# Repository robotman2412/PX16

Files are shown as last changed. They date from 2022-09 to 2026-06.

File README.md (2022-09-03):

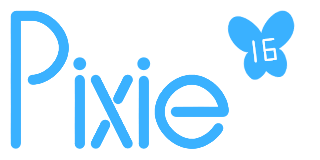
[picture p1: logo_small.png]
Logo image


# Pixie 16
A 16-bit simple-as-possible\* RISC CPU.
Has conditional `MOV` instructions (which is also how branching happens),
And a few math instructions.

Has 4 general registers: `R0`, `R1`, `R2`, `R3`
And 3 special registers: `ST` (stack register), `PF` (flags register), `PC` (program counter)

64K x 16bit memory.

### Note:
RISC is not equal to RISC-V.

PX16 cannot address bytes.

# TODO
Stuf i do be workin on:
- PCB edition
- Emulator
- Finalise MMIO Hardware
- C Compiler

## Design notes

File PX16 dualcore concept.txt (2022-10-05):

Requirements for multicore:
	- Alt core startup system
	- Core detection
	- Mutex hardware
	- Memory sharing plan

Nice-to-haves:
	- Core affine MMIO copies
	- Core affine RAM
	- Inter-Processor interrupts
	- Dual port RAM

When all the nice to haves are included, the cores are linked by:
	RAM (non-core affine part)
	Inter-Processor interrupts
	Mutex hardware

Viability:
	Dual port RAM chips are expensive, which means most likely dedicated circuitry.
	Dual port ROM is basically not a thing, which means that ROM must be copied before use.
	
	Creating two copies of all MMIO will be expensive and time-consuming because combined MMIO might be more complex than the core.
	
	Correctly coded software should not be affected, despite OS changes.

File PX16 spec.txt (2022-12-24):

Instruction format:
15.. .... .... ...0
YXXX BBBA AAOO OOOO

O: Opcode
A: A operand register
B: B operand register
X: Complex operand mode
Y: Apply complex operand to B instead of A

            .0  .1  .2  .3  .4  .5  .6  .7
0.  MATH2   ADD SUB CMP AND OR  XOR
1.  MATH2C  ADD SUB CMP AND OR  XOR
2.  MATH1   INC DEC CMP             SHL SHR
3.  MATH1C  INC DEC CMP             SHL SHR
4.  MOV.C   ULT UGT SLT SGT EQ  CS  1
5.  MOV.C   UGE ULE SGE SLE NE  CC  JSR CX
6.  LEA.C   ULT UGT SLT SGT EQ  CS  1
7.  LEA.C   UGE ULE SGE SLE NE  CC  JSR

Note: Because CMP is much like SUB, CMP is still valid for MATH1.

Registers:
R0, R1, R2, R3, ST, PF, PC, imm

Addressing modes:
    0: AR0  [A+R0]
    1: AR1  [A+R1]
    2: AR2  [A+R2]
    3: AR3  [A+R3]
    4: AST  [A+ST]
    5: MEM  [A]
    6: APC  [A+PC]
    7: IMM   A

Conditions:
    0:    ULT: Unsigned A < B; ~UCout ~Zero
    1:    UGT: Unsigned A > B;  UCout ~Zero
    2:    SLT: Signed A < B;   ~SCout ~Zero
    3:    SGT: Signed A > B;    SCout ~Zero
    4:    EQ:  Unsigned A = B;         Zero
    5:    CS:  Unsigned cout;   UCout
    6:    1:   Always true
    7:    -
    8-13: Opposite condition of 0-5
    14:   JSR: Used for creating subroutines
    15:   CX:  Used for carry extend

Enable IRQs and NMIs:
    OR  PF, 0x0003

Disable IRQs:
    AND PF, 0xfffd

Jump:
    LEA PC, [PC+imm]

Jump to subroutine:
    LEA.JSR PC, [PC+imm]

Return from subroutine:
    MOV PC, [ST]

Return from interrupt:
    // PX16 will not trigger interrupts immediately after this instruction.
    // This allows the return from interrupt to be 2 typical instructions.
    MOV PF, [ST]
    MOV PC, [ST]

Flag register (PF) layout:
15.. .... .... ...0
SUZ. .... .... PSIN
S: Signed carry out
U: Unsigned carry out
Z: Zero
P: Interrupt in progress
S: Interrupt was software triggered
I: IRQ enable
N: NMI enable

States:
    Boot: Load address 2 and set PC to it's value
        Boot 0: Set PC to 1
        Boot 1: Set PC to *2 by means of *(PC+1)
    Load:
        Load 0: Fetch and decode instruction
        Load 1: Fetch imm0
        Load 2: Fetch imm1
    Push: Pre-decrement ST
    Jsr:  Push PC to stack
    Addr: Address calculation and memory access
    Act:  Enact the instruction
    Pop:  Post-increment ST
    Intr:
        Intr 0: Pre-decrement ST
        Intr 1: Push PC to stack
        Intr 2: Pre-decrement ST
        Intr 3: Push PF to stack and set interrupt in progress flag
        Intr 4: Set PC to interrupt vector (*0 for IRQ, *1 for NMI)

State matrix:
            INC WR  WM  RM  W       AIA AIB AXA AXB Cin     ADD OR  XOR SHL SHR     A   B   Dst Si0 Si1
    Boot 0: -   1   -   -   -       -   -   -   1   1       1   -   -   -   -       6   -   6   -   -
    Boot 1: -   1   -   1   -       -   -   -   1   1       1   -   -   -   -       6   -   6   -   -
    
    Load 0: 1   -   -   1   -       -   -   1   -   -       -   1   -   -   -       -   6   -   -   -
    Load 1: 1   -   -   1   -       -   -   1   -   -       -   1   -   -   -       -   6   -   1   -
    Load 2: 1   -   -   1   -       -   -   1   -   -       -   1   -   -   -       -   6   -   -   1
    
    Push:   -   1   -   -   -       -   1   -   1   -       1   -   -   -   -       4   -   4   -   -
    Jsr:    -   -   1   -   -       -   -   1   -   -       -   1   -   -   -       -   6   -   -   -
    Addr:   Depends on addressing mode
    Mov:    Depends on opcode
    Act:    Depends on opcode
    Pop:    -   1   -   -   -       -   -   -   1   1       1   -   -   -   -       4   -   4   -   -
    
    Intr 0: -   1   -   -   -       -   1   -   1   -       1   -   -   -   -       4   -   4   -   -
    Intr 1: -   -   1   -   -       -   -   1   -   -       -   1   -   -   -       -   6   -   -   -
    Intr 2: -   1   -   -   -       -   1   -   1   -       1   -   -   -   -       4   -   4   -   -
    Intr 3: -   -   1   -   -       -   -   1   -   -       -   1   -   -   -       -   5   -   -   -
    Intr 4: -   1   -   1   -       -   -   1   -   -       -   1   -   -   -       -   -   6   -   -
    
Addressing matrix:
    AR*     -   -   -   1   -       -   -   -   -   -       1   -   -   -   -       X   Ry  -   -   -
    IMM:    Skip addr
    MOV     -   -   -   -   -       -   -   1   -   -       -   1   -   -   -       -   B   -   -   -
    MEM     -   -   -   1   -       -   -   1   -   -       -   1   -   -   -       -   Ry  -   -   -
    
    LEA     -   -   -   0   1       -   -   -   -   -       -   -   -   -   -       -   -   A   -   -
    MOV     -   -   -   -   1       -   -   -   -   -       -   -   -   -   -       -   -   A   -   -
    ACT     -   -   -   -   -       -   -   -   -   -       -   -   -   -   -       -   -   -   !Y  Y
    
Calculation matrix:
    ADD     -   -   -   -   1       -   -   -   -   -       1   -   -   -   -       A   B   A   -   -
    SUB     -   -   -   -   1       -   1   -   -   1       1   -   -   -   -       A   B   A   -   -
    CMP     -   -   -   -   -       -   1   -   -   1       1   -   -   -   -       A   B   A   -   -
    AND     -   -   -   -   1       1   1   -   -   -       -   1   -   -   -       A   B   A   -   -
    OR      -   -   -   -   1       -   -   -   -   -       -   1   -   -   -       A   B   A   -   -
    XOR     -   -   -   -   1       -   -   -   -   -       -   -   1   -   -       A   B   A   -   -
    
    INC     -   -   -   -   1       -   -   -   1   1       1   -   -   -   -       A   B   A   -   -
    DEC     -   -   -   -   1       -   1   -   1   -       1   -   -   -   -       A   B   A   -   -
    CMP     -   -   -   -   -       -   1   -   1   -       1   -   -   -   -       A   B   A   -   -
    SHL     -   -   -   -   1       -   -   -   1   -       -   -   -   1   -       A   B   A   -   -
    SHR     -   -   -   -   1       -   -   -   1   -       -   -   -   -   1       A   B   A   -   -
    
    MOV     Skip act
    LEA     Skip act

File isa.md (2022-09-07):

Logo image

# Pixie 16 instruction set

Pixie 16 is a RISC 16-bit CPU with a 16-bit address space.
It addresses 65536 times 16-bit words (bytes unsupported).

Also referred to by "PX16", it is a von neumann architecture, which means that instructions and data use the same bus.
Pixie 16 reads memory during instruction loading time, and the actual execution of opcodes themselves takes only one of the on average four cycles it takes to run an instruction.

Instructions take between 2 (minimum) and 5 (maximum) cycles to run,
and instructions with constant parameter have the parameter words immediately follow the instruction word.

PX16 does not necessarily need to deal with endianness, but is specified to be little-endian (lowest word comes first in memory) when applicable. Therfore, PX16 binaries stored on disk should also be little-endian when they use their two bytes to encode a 16-bit word.

The character set is ASCII and text outside that range should be UTF-16 little-endian unicode.

# Registers
Pixie  has 4 general and 3 special registers:
| name | code | description
| :--- | :--- | :---
| R0 | 00 | General-purpose register.
| R1 | 01 | General-purpose register.
| R2 | 02 | General-purpose register.
| R3 | 03 | General-purpose register.
| ST | 04 | Stack pointer.
| PF | 05 | Flags register.
| PC | 06 | Program counter.

# Encoding
The instruction is comprised of 5 bitfields filling up a word:
| name | range | bitmask | description
| :--- | :---- | :--- | :---
| `y`  | 15 | `y... .... .... ....` | Addressing selector.
| `x`  | 14-12 | `.xxx .... .... ....` | Addressing mode.
| `b`  | 11-9  | `.... bbb. .... ....` | Second "B" operand.
| `a`  | 8-6 | `.... ...a aa.. ....` | First "A" operand.
| `o`  | 5-0 | `.... .... ..oo oooo` | Opcode.
- `y` selects which operand `x` will apply to:
  - `y=0` means `x` applies to A,
  - `y=1` means `x` applies to B.
- `x` describes the addressing mode to use ([see: Addressing](#addressing))
- `b` and `a` describe which register to use for their respective operands.
- `o` describes which opcode to run ([see: Opcodes](#opcodes))

# Opcodes
Pixie 16 has 4 major categories of instructions, filling `o` field of the instruction:
| type  | start | end | description
| :---- | :---- | :-- | :---
| MATH2 | 000 | 017 | Math with two operands.
| MATH1 | 020 | 037 | Math with one operand.
| MOV | 040 | 057 | Data move, with optional condition.
| LEA | 060 | 077 | Load effective address, more restrictive.

## MATH2 type opcodes
MATH2 opcodes take 2 parameters and modify the A parameter with the result.
`CMP` is an exception to this rule.

The code is for the `o` field with carry in = default.
The CC code is with carry in = carry out flag.
| name | code | code (CC) | description
| :--- | :--- | :--- | :---
| ADD  | 000  | 010 | Adds B to A.
| SUB  | 001  | 011 | Subtracts B from A.
| CMP  | 002  | 012 | Compares A to B for use in conditional MOV or LEA.
| AND  | 003  | 013 | Bitwise ANDs A by B.
| OR | 004  | 014 | Bitwise ORs A with B.
| XOR  | 005  | 015 | Bitwise XORs A by B.

## MATH1 type opcodes
MATH1 opcodes take 1 parameter and ignore the B parameter, which is substituted with 1.
Again, `CMP1` does not modify the A parameter.

| name | code | code (CC) | description
| :--- | :--- | :--- | :---
| INC  | 020  | 030 | Adds 1 to A.
| DEC  | 021  | 031 | Subtracts 1 from A.
| CMP1 | 022  | 032 | Compares A against 1.
| SHL  | 026  | 036 | Bitwise shifts A left one position. (A = A * 2)
| SHR  | 027  | 037 | Bitwise shifts A right one position. (A = A / 2)

## MOV type opcodes
MOV opcodes mostly do the same thing: copy B into A.
However, MOV opcodes also have a condition to satisfy, which enables their behaviour (except push/pop which always happens).

| name | code | description
| :--- | :--- | :---
| MOV.ULT | 040  | Condition: A < B (unsigned).
| MOV.UGT | 041  | Condition: A > B (unsigned).
| MOV.SLT | 042  | Condition: A < B (signed).
| MOV.SGT | 043  | Condition: A > B (signed).
| MOV.EQ  | 044  | Condition: A = B (zero flag = 1).
| MOV.CS  | 045  | Condition: carry out flag = 1 (unsigned).
| MOV | 046  | Unconditional.
| MOV.UGE | 050  | Condition: A >= B (unsigned).
| MOV.ULE | 051  | Condition: A <= B (unsigned).
| MOV.SGE | 052  | Condition: A >= B (signed).
| MOV.SLE | 053  | Condition: A <= B (signed).
| MOV.NE  | 054  | Condition: A != B (zero flag = 0).
| MOV.CC  | 055  | Condition: carry out flag = 0 (unsigned).
| MOV.JSR | 056  | Special: jump to subroutine (push PC to stack before performing MOV).
| MOV.CX  | 057  | Special: carry extend (A is filled with highest bit of B).

## LEA type opcodes
LEA opcodes are identical to MOV, with the exception that `LEA.CX` doesn't exist.
LEA opcodes load the effective address of B into A, instead of the value stored there.
This means that LEA always has a _register_ for A and always has a _memory operand_ for B.

# Adressing
PX16 opcodes aren't exceptionally smart on their own, and programs will heavily rely on more complex addressing features to compensate.

All 7 registers can be used in all instructions, but an extra `imm` register appears here.
These have code 07, and are written as any one of: `label`, `label+0123`, `0123`, etc.

The `imm` registers are initialised to the specified constant at instruction load time, and there is one `imm` for operand A, and another for operand B. Storing to the `imm` registers results in undefined behaviour, which makes `cmp` and `cmp1` the only valid instructions with `imm` for operand A.

The registers are then combined with one of the following addressing modes, which is stored in the `x` field:
| type | syntax | code | description
| :--- | :--- | :--- | :---
| Memory  | `[... + R0]` | 00 | Address is value of `R0` + the affected operand.
| Memory  | `[... + R1]` | 01 | Address is value of `R1` + the affected operand.
| Memory  | `[... + R2]` | 02 | Address is value of `R2` + the affected operand.
| Memory  | `[... + R3]` | 03 | Address is value of `R3` + the affected operand.
| Memory  | `[... + ST]` | 04 | Address is value of `ST` + the affected operand.
| Memory  | `[...]` | 05 | Address is value of the affected operand.
| Memory  | `[... + PC]` | 06 | Address is value of `PC` + the affected operand.
| Register | `...` | 07 | No change to affected operand.

# The stack
When combined, one of the addressing modes has a special effect:
The stack push/pop operation.
Represented by `[ST]`, this pushes to the stack when the A parameter, or pops from it when the B parameter.
This mode doesn't make sense to use in `MATH1` or as A parameter to `MATH2`.

The stack grown down in the address space in a pre-decrement way.
This means that the top value in the stack is at `[ST+0x0000]`.

# Implementation of functions
PX16 functions follow simple calling conventions
- When the arguments total up to 4 words, registers are used for passing the arguments.
- Otherwise, the stack is used, where the last parameter is pushed first.
- On return, the same rules apply to the return value.
- Any registers not used to pass args or return should be preserved by the callee.

Here is a typical function based on the following C:
```c
int multiplyByTwo(int value) {
    return value << 1;
}
```
And assembly:
```
multiplyByTwo:
    // Preserve other registers.
    MOV [ST], R3
    MOV [ST], R2
    MOV [ST], R1
    // value << 1
    SHL R0
    // Restore other registers.
    mov R1, [ST]
    mov R2, [ST]
    mov R3, [ST]
    // return
    MOV PC, [ST]
```

# Interrupt handling
When an interrupt occurs, the PC followed by PF are pushed to the stack.
Then, [0x0000] (for NMI type) or [0x0001] (for IRQ type) is loaded into the PC.

At this point, it is up to the interrupt handler to do it's things, after which it returns with the following:
```
    // Restore flags, which reenables interrupts after the return.
    MOV PF, [ST]
    // Return by popping PC off the stack.
    MOV PC, [ST]
```

# Initial startup
After reset signal clears, Pixie 16 takes 1-2 cycles to load the entrypoint address from [0x0002].
At this point, all registers are zero, including PF, which means that Pixie 16 starts by jumping to the entrypoint with interrupts disabled.

Pixie 16 (and any occasional additional hardware) are designed  such that 0 is the "safe state", which means that the hardware or CPU are in a defined state when registers are all zero.

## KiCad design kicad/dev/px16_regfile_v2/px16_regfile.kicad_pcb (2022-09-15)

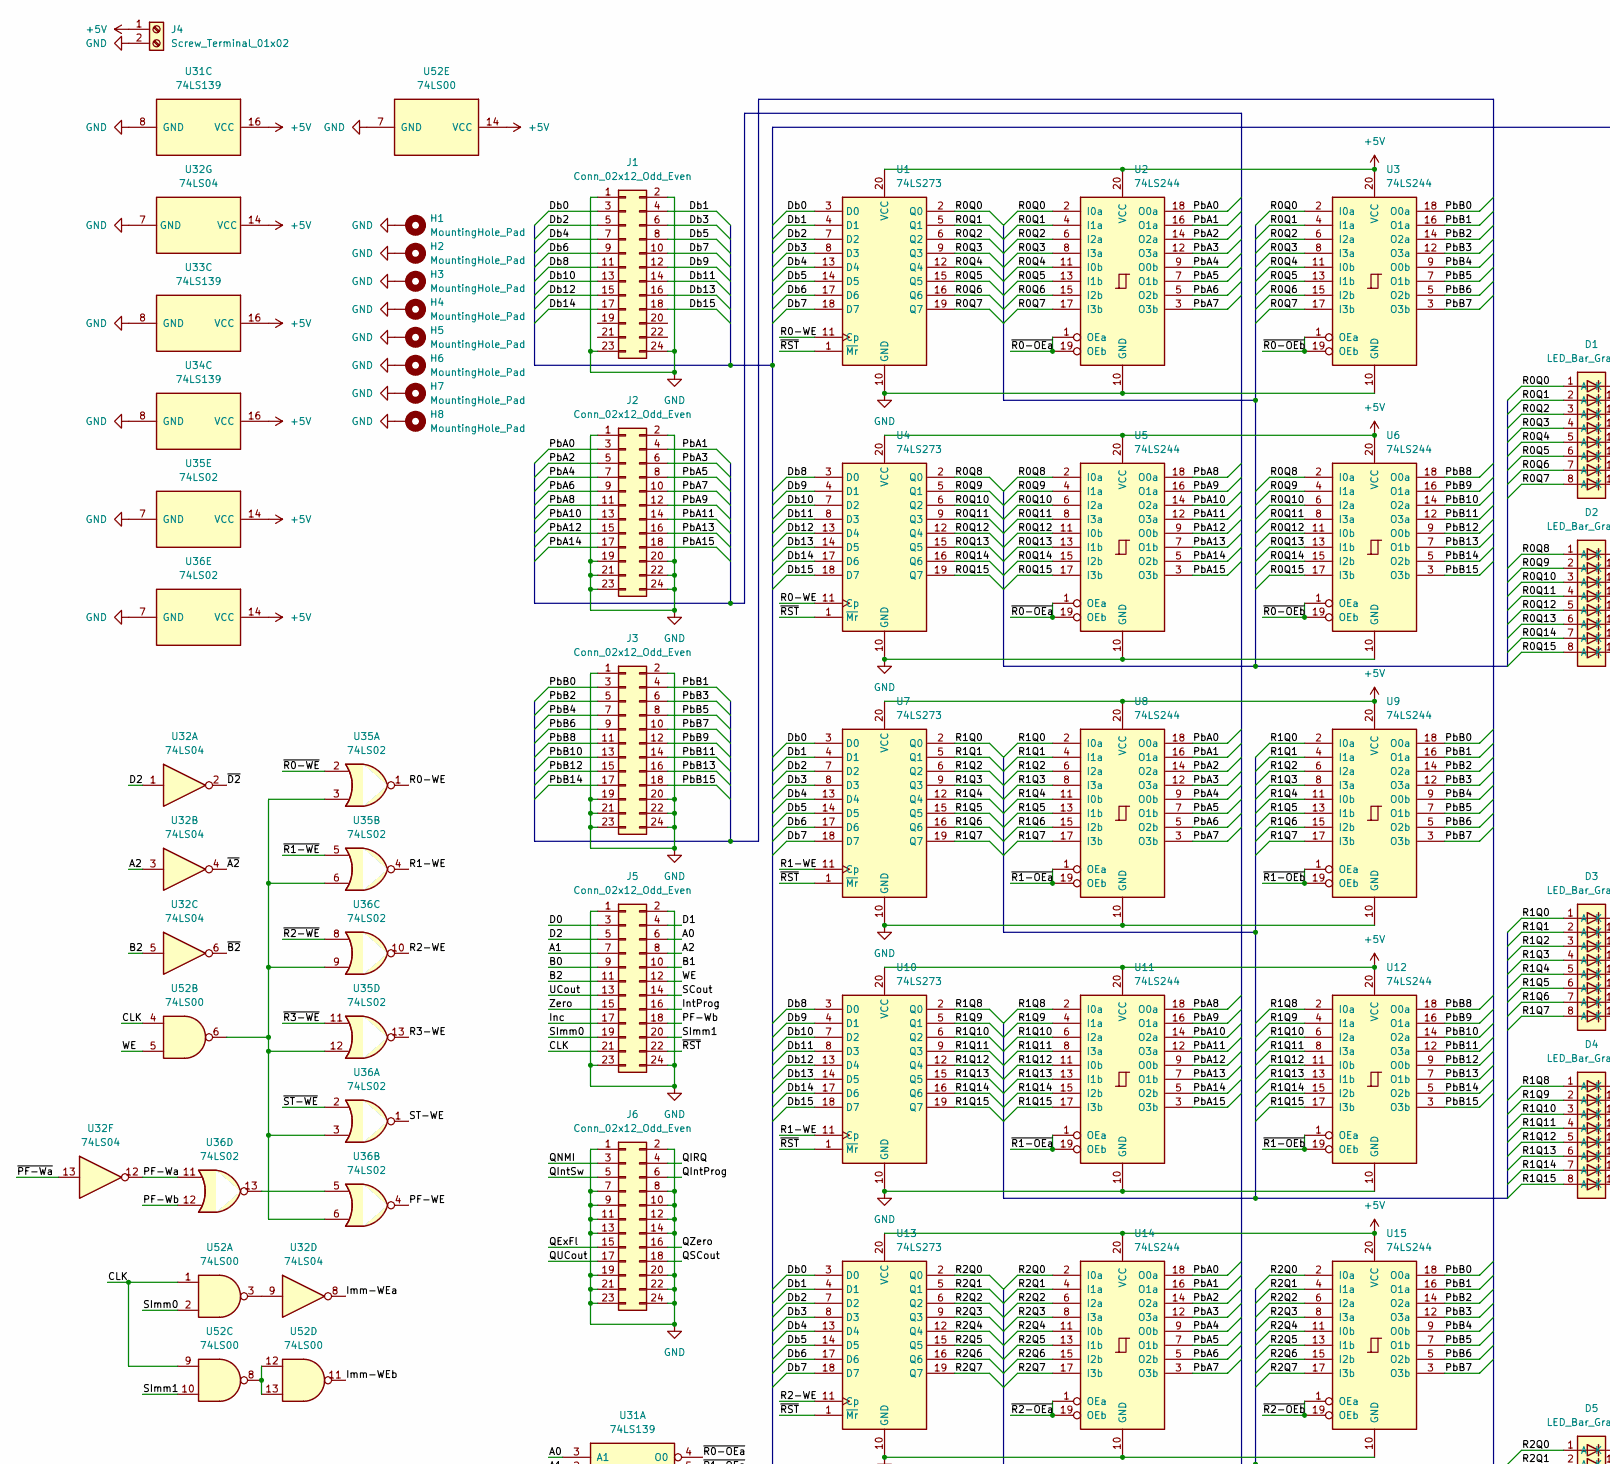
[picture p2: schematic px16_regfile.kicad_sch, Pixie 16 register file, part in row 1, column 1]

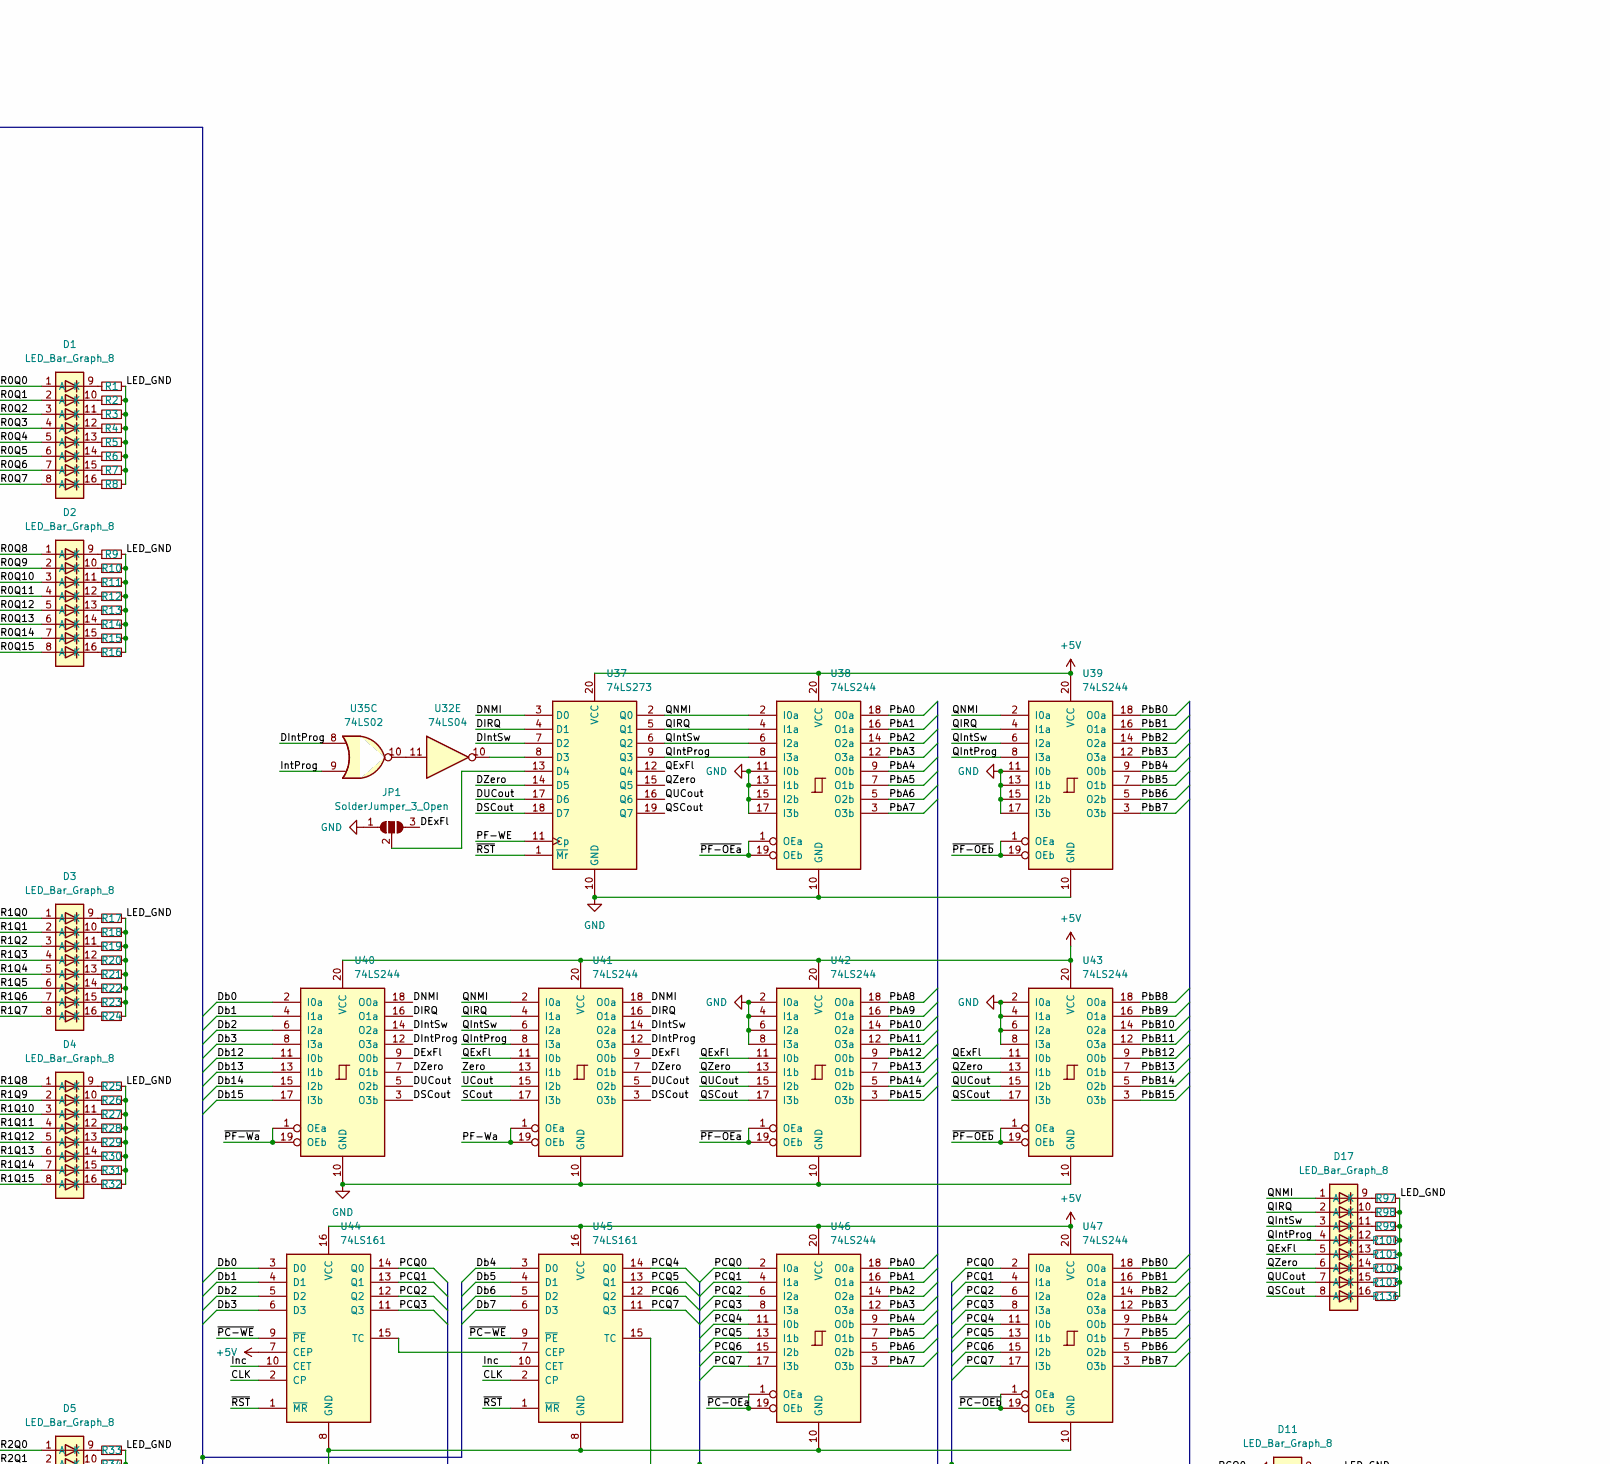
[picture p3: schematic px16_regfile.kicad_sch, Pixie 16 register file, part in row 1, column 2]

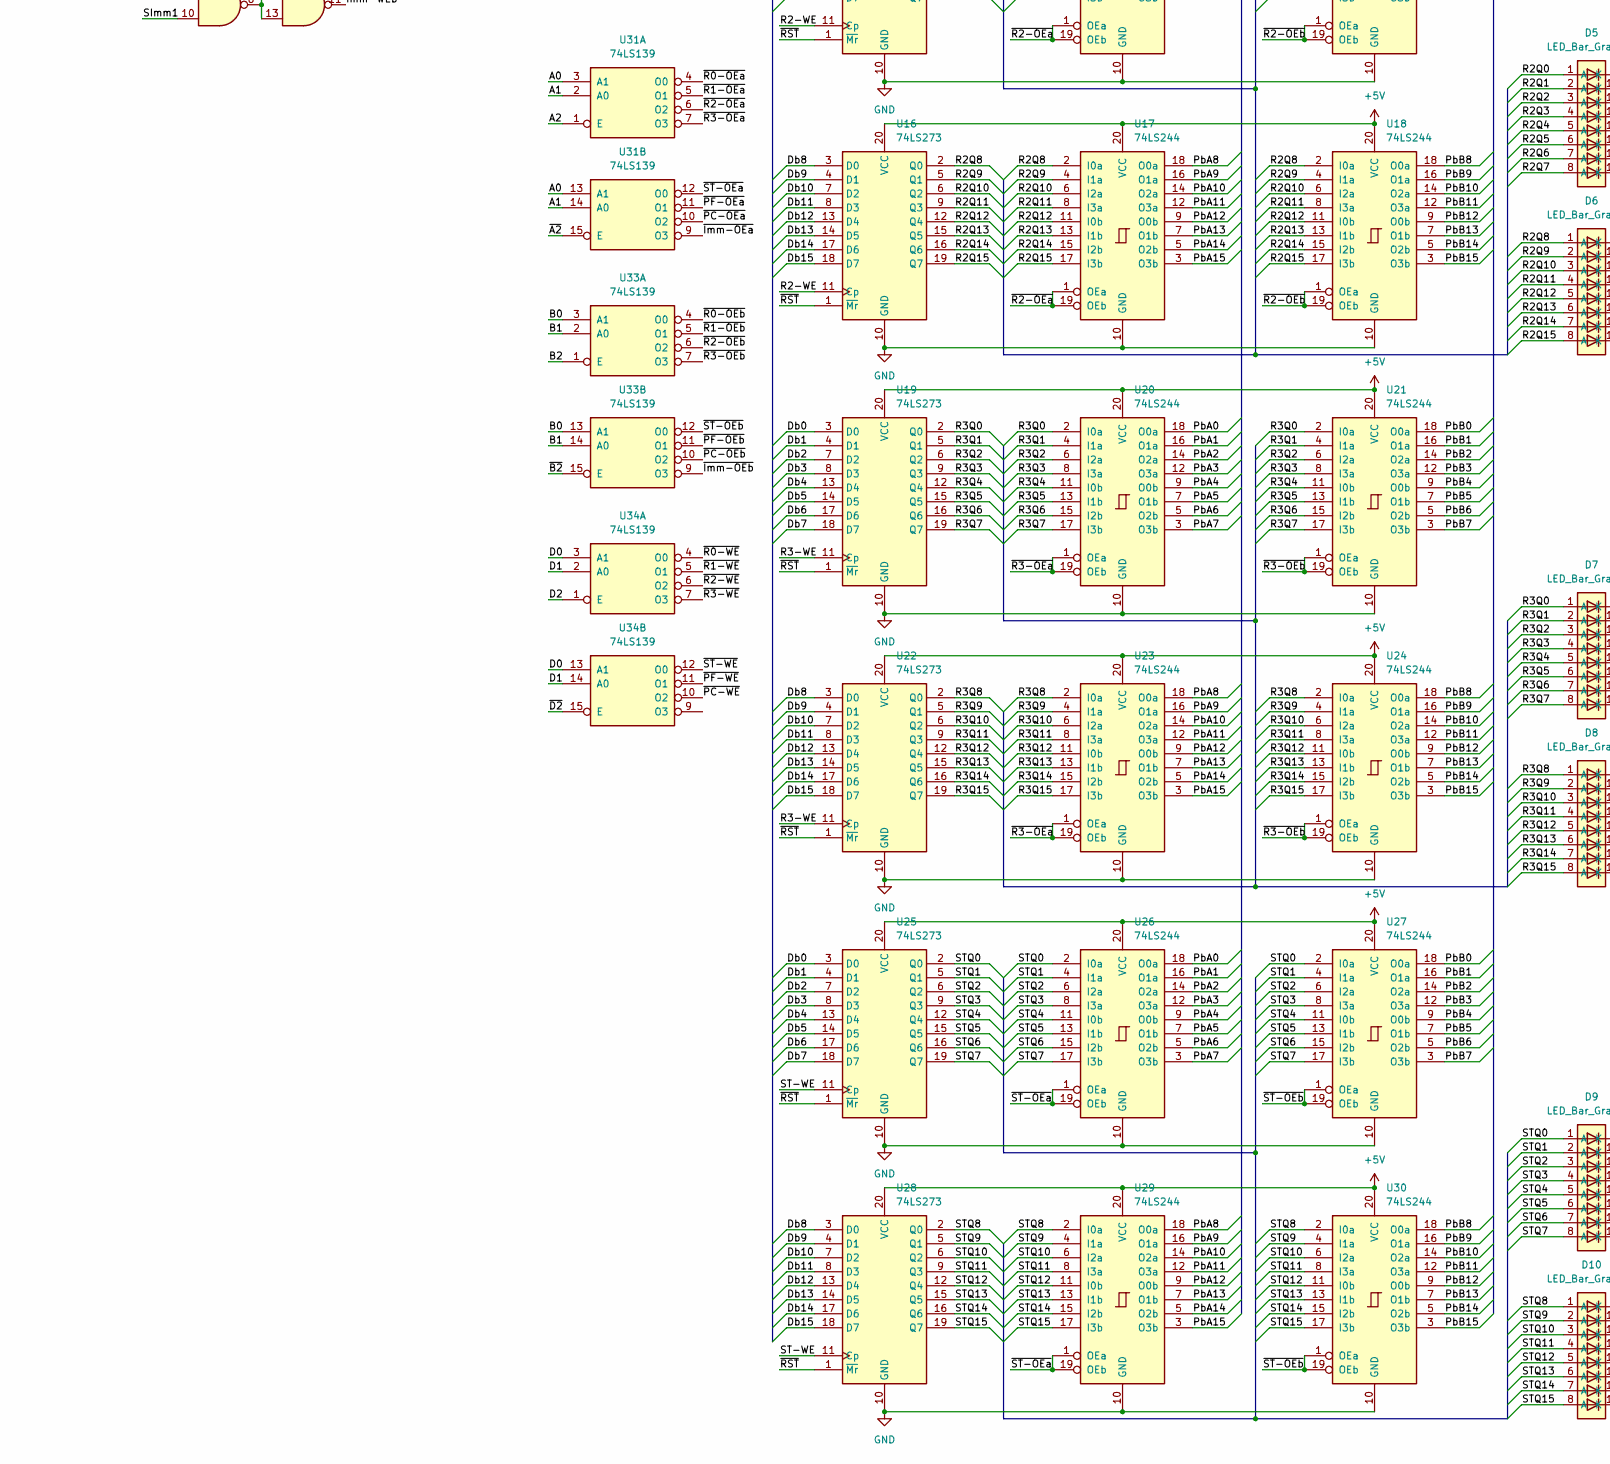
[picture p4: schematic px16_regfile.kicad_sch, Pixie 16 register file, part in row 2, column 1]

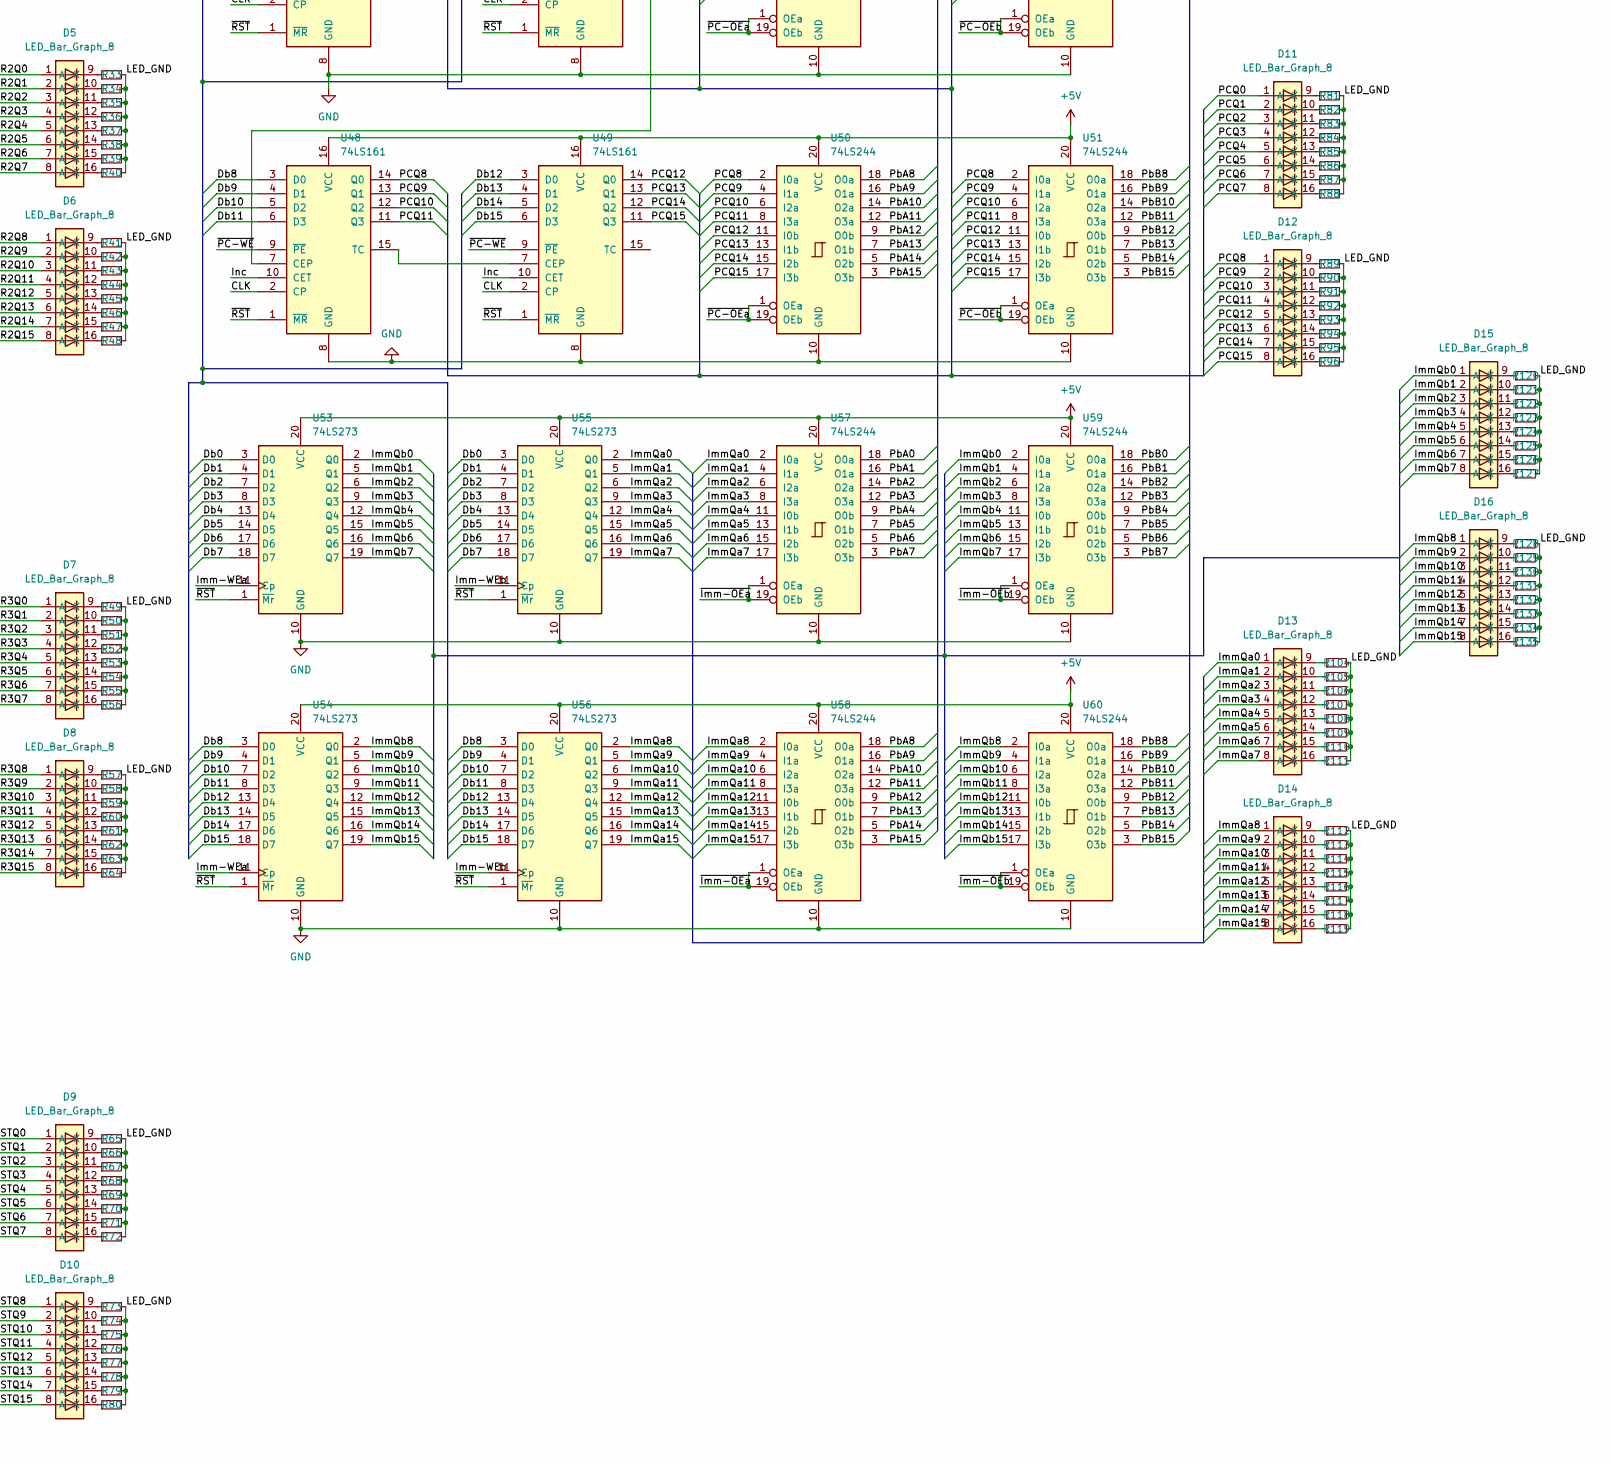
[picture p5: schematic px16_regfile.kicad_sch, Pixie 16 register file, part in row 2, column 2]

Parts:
D1, D2, D3, D4, D5, D6, D7, D8, D9, D10, D11, D12, D13, D14, D15, D16, D17: LED_Bar_Graph_8; DIP-16_W7.62mm_Socket
H1, H2, H3, H4, H5, H6, H7, H8: MountingHole_Pad; MountingHole_3mm_Pad
J1, J2, J3, J5, J6: Conn_02x12_Odd_Even; PinHeader_2x12_P2.54mm_Vertical
J4: Screw_Terminal_01x02; TerminalBlock_bornier-2_P5.08mm
JP1: SolderJumper_3_Open; SolderJumper-3_P1.3mm_Open_Pad1.0x1.5mm_NumberLabels
R1, R2, R3, R4, R5, R6, R7, R8, R9, R10, R11, R12, R13, R14, R15, R16, R17, R18, R19, R20, R21, R22, R23, R24, R25, R26, R27, R28, R29, R30, R31, R32, R33, R34, R35, R36, R37, R38, R39, R40, R41, R42, R43, R44, R45, R46, R47, R48, R49, R50, R51, R52, R53, R54, R55, R56, R57, R58, R59, R60, R61, R62, R63, R64, R65, R66, R67, R68, R69, R70, R71, R72, R73, R74, R75, R76, R77, R78, R79, R80, R81, R82, R83, R84, R85, R86, R87, R88, R89, R90, R91, R92, R93, R94, R95, R96, R97, R98, R99, R100, R101, R102, R103, R104, R105, R106, R107, R108, R109, R110, R111, R112, R113, R114, R115, R116, R117, R118, R119, R120, R121, R122, R123, R124, R125, R126, R127, R128, R129, R130, R131, R132, R133, R134, R135, R136: R; R_Axial_DIN0207_L6.3mm_D2.5mm_P2.54mm_Vertical
U1, U4, U7, U10, U13, U16, U19, U22, U25, U28, U37, U53, U54, U55, U56: 74LS273; SOP-20_7.5x12.8mm_P1.27mm
U2, U3, U5, U6, U8, U9, U11, U12, U14, U15, U17, U18, U20, U21, U23, U24, U26, U27, U29, U30, U38, U39, U40, U41, U42, U43, U46, U47, U50, U51, U57, U58, U59, U60: 74LS244; SOP-20_7.5x12.8mm_P1.27mm
U31, U33, U34: 74LS139; SOIC-16W_7.5x10.3mm_P1.27mm
U32: 74LS04; SOIC-14W_7.5x9mm_P1.27mm
U35, U36: 74LS02; SOIC-14W_7.5x9mm_P1.27mm
U44, U45, U48, U49: 74LS161; SOIC-16W_7.5x10.3mm_P1.27mm
U52: 74LS00; SOIC-14W_7.5x9mm_P1.27mm

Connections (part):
+5V: J4.1, U1.20 (VCC), U2.20 (VCC), U3.20 (VCC), U4.20 (VCC), U5.20 (VCC), U6.20 (VCC), U7.20 (VCC), U8.20 (VCC), U9.20 (VCC), U10.20 (VCC), U11.20 (VCC), U12.20 (VCC), U13.20 (VCC), U14.20 (VCC), U15.20 (VCC), U16.20 (VCC), U17.20 (VCC), U18.20 (VCC), U19.20 (VCC), U20.20 (VCC), U21.20 (VCC), U22.20 (VCC), U23.20 (VCC), U24.20 (VCC), U25.20 (VCC), U26.20 (VCC), U27.20 (VCC), U28.20 (VCC), U29.20 (VCC), U30.20 (VCC), U31.16 (VCC), U32.14 (VCC), U33.16 (VCC), U34.16 (VCC), U35.14 (VCC), U36.14 (VCC), U37.20 (VCC), U38.20 (VCC), U39.20 (VCC), U40.20 (VCC), U41.20 (VCC), U42.20 (VCC), U43.20 (VCC), U44.7 (CEP), U44.16 (VCC), U45.16 (VCC), U46.20 (VCC), U47.20 (VCC), U48.16 (VCC), U49.16 (VCC), U50.20 (VCC), U51.20 (VCC), U52.14 (VCC), U53.20 (VCC), U54.20 (VCC), U55.20 (VCC), U56.20 (VCC), U57.20 (VCC), U58.20 (VCC), U59.20 (VCC), U60.20 (VCC)
/A0: J5.6, U31.3 (A1), U31.13 (A1)
/A1: J5.7, U31.2 (A0), U31.14 (A0)
/A2: J5.8, U31.1 (E), U32.3
/B0: J5.9, U33.3 (A1), U33.13 (A1)
/B1: J5.10, U33.2 (A0), U33.14 (A0)
/B2: J5.11, U32.5, U33.1 (E)
/CLK: J5.21, U44.2 (CP), U45.2 (CP), U48.2 (CP), U49.2 (CP), U52.1, U52.4, U52.9
/D0: J5.3, U34.3 (A1), U34.13 (A1)
/D1: J5.4, U34.2 (A0), U34.14 (A0)
/D2: J5.5, U32.1, U34.1 (E)
/DExFl: JP1.3 (B), U40.9 (O0b), U41.9 (O0b)
/DIRQ: U37.4 (D1), U40.16 (O1a), U41.16 (O1a)
/DIntProg: U35.8, U40.12 (O3a), U41.12 (O3a)
/DIntSw: U37.7 (D2), U40.14 (O2a), U41.14 (O2a)
/DNMI: U37.3 (D0), U40.18 (O0a), U41.18 (O0a)
/DSCout: U37.18 (D7), U40.3 (O3b), U41.3 (O3b)
/DUCout: U37.17 (D6), U40.5 (O2b), U41.5 (O2b)
/DZero: U37.14 (D5), U40.7 (O1b), U41.7 (O1b)
/Db0: J1.3, U1.3 (D0), U7.3 (D0), U13.3 (D0), U19.3 (D0), U25.3 (D0), U40.2 (I0a), U44.3 (D0), U53.3 (D0), U55.3 (D0)
/Db1: J1.4, U1.4 (D1), U7.4 (D1), U13.4 (D1), U19.4 (D1), U25.4 (D1), U40.4 (I1a), U44.4 (D1), U53.4 (D1), U55.4 (D1)
/Db2: J1.5, U1.7 (D2), U7.7 (D2), U13.7 (D2), U19.7 (D2), U25.7 (D2), U40.6 (I2a), U44.5 (D2), U53.7 (D2), U55.7 (D2)
/Db3: J1.6, U1.8 (D3), U7.8 (D3), U13.8 (D3), U19.8 (D3), U25.8 (D3), U40.8 (I3a), U44.6 (D3), U53.8 (D3), U55.8 (D3)
/Db4: J1.7, U1.13 (D4), U7.13 (D4), U13.13 (D4), U19.13 (D4), U25.13 (D4), U45.3 (D0), U53.13 (D4), U55.13 (D4)
/Db5: J1.8, U1.14 (D5), U7.14 (D5), U13.14 (D5), U19.14 (D5), U25.14 (D5), U45.4 (D1), U53.14 (D5), U55.14 (D5)
/Db6: J1.9, U1.17 (D6), U7.17 (D6), U13.17 (D6), U19.17 (D6), U25.17 (D6), U45.5 (D2), U53.17 (D6), U55.17 (D6)
/Db7: J1.10, U1.18 (D7), U7.18 (D7), U13.18 (D7), U19.18 (D7), U25.18 (D7), U45.6 (D3), U53.18 (D7), U55.18 (D7)
/Db8: J1.11, U4.3 (D0), U10.3 (D0), U16.3 (D0), U22.3 (D0), U28.3 (D0), U48.3 (D0), U54.3 (D0), U56.3 (D0)
/Db9: J1.12, U4.4 (D1), U10.4 (D1), U16.4 (D1), U22.4 (D1), U28.4 (D1), U48.4 (D1), U54.4 (D1), U56.4 (D1)
/Db10: J1.13, U4.7 (D2), U10.7 (D2), U16.7 (D2), U22.7 (D2), U28.7 (D2), U48.5 (D2), U54.7 (D2), U56.7 (D2)
/Db11: J1.14, U4.8 (D3), U10.8 (D3), U16.8 (D3), U22.8 (D3), U28.8 (D3), U48.6 (D3), U54.8 (D3), U56.8 (D3)
/Db12: J1.15, U4.13 (D4), U10.13 (D4), U16.13 (D4), U22.13 (D4), U28.13 (D4), U40.11 (I0b), U49.3 (D0), U54.13 (D4), U56.13 (D4)
/Db13: J1.16, U4.14 (D5), U10.14 (D5), U16.14 (D5), U22.14 (D5), U28.14 (D5), U40.13 (I1b), U49.4 (D1), U54.14 (D5), U56.14 (D5)
/Db14: J1.17, U4.17 (D6), U10.17 (D6), U16.17 (D6), U22.17 (D6), U28.17 (D6), U40.15 (I2b), U49.5 (D2), U54.17 (D6), U56.17 (D6)
/Db15: J1.18, U4.18 (D7), U10.18 (D7), U16.18 (D7), U22.18 (D7), U28.18 (D7), U40.17 (I3b), U49.6 (D3), U54.18 (D7), U56.18 (D7)
/Imm-WEa: U32.8, U53.11 (Cp), U54.11 (Cp)
/Imm-WEb: U52.11, U55.11 (Cp), U56.11 (Cp)
/ImmQa0: D13.1 (A), U55.2 (Q0), U57.2 (I0a)
/ImmQa1: D13.2 (A), U55.5 (Q1), U57.4 (I1a)
/ImmQa2: D13.3 (A), U55.6 (Q2), U57.6 (I2a)
/ImmQa3: D13.4 (A), U55.9 (Q3), U57.8 (I3a)
/ImmQa4: D13.5 (A), U55.12 (Q4), U57.11 (I0b)
/ImmQa5: D13.6 (A), U55.15 (Q5), U57.13 (I1b)
/ImmQa6: D13.7 (A), U55.16 (Q6), U57.15 (I2b)
/ImmQa7: D13.8 (A), U55.19 (Q7), U57.17 (I3b)
/ImmQa8: D14.1 (A), U56.2 (Q0), U58.2 (I0a)
/ImmQa9: D14.2 (A), U56.5 (Q1), U58.4 (I1a)
/ImmQa10: D14.3 (A), U56.6 (Q2), U58.6 (I2a)
/ImmQa11: D14.4 (A), U56.9 (Q3), U58.8 (I3a)
/ImmQa12: D14.5 (A), U56.12 (Q4), U58.11 (I0b)
/ImmQa13: D14.6 (A), U56.15 (Q5), U58.13 (I1b)
/ImmQa14: D14.7 (A), U56.16 (Q6), U58.15 (I2b)
/ImmQa15: D14.8 (A), U56.19 (Q7), U58.17 (I3b)
/ImmQb0: D15.1 (A), U53.2 (Q0), U59.2 (I0a)
/ImmQb1: D15.2 (A), U53.5 (Q1), U59.4 (I1a)
/ImmQb2: D15.3 (A), U53.6 (Q2), U59.6 (I2a)
/ImmQb3: D15.4 (A), U53.9 (Q3), U59.8 (I3a)
/ImmQb4: D15.5 (A), U53.12 (Q4), U59.11 (I0b)
/ImmQb5: D15.6 (A), U53.15 (Q5), U59.13 (I1b)
/ImmQb6: D15.7 (A), U53.16 (Q6), U59.15 (I2b)
/ImmQb7: D15.8 (A), U53.19 (Q7), U59.17 (I3b)
/ImmQb8: D16.1 (A), U54.2 (Q0), U60.2 (I0a)
/ImmQb9: D16.2 (A), U54.5 (Q1), U60.4 (I1a)
/ImmQb10: D16.3 (A), U54.6 (Q2), U60.6 (I2a)
/ImmQb11: D16.4 (A), U54.9 (Q3), U60.8 (I3a)
/ImmQb12: D16.5 (A), U54.12 (Q4), U60.11 (I0b)
/ImmQb13: D16.6 (A), U54.15 (Q5), U60.13 (I1b)
/ImmQb14: D16.7 (A), U54.16 (Q6), U60.15 (I2b)
/ImmQb15: D16.8 (A), U54.19 (Q7), U60.17 (I3b)
/Inc: J5.17, U44.10 (CET), U45.10 (CET), U48.10 (CET), U49.10 (CET)
/IntProg: J5.16, U35.9
/LED_GND: R1.2, R2.2, R3.2, R4.2, R5.2, R6.2, R7.2, R8.2, R9.2, R10.2, R11.2, R12.2, R13.2, R14.2, R15.2, R16.2, R17.2, R18.2, R19.2, R20.2, R21.2, R22.2, R23.2, R24.2, R25.2, R26.2, R27.2, R28.2, R29.2, R30.2, R31.2, R32.2, R33.2, R34.2, R35.2, R36.2, R37.2, R38.2, R39.2, R40.2, R41.2, R42.2, R43.2, R44.2, R45.2, R46.2, R47.2, R48.2, R49.2, R50.2, R51.2, R52.2, R53.2, R54.2, R55.2, R56.2, R57.2, R58.2, R59.2, R60.2, R61.2, R62.2, R63.2, R64.2, R65.2, R66.2, R67.2, R68.2, R69.2, R70.2, R71.2, R72.2, R73.2, R74.2, R75.2, R76.2, R77.2, R78.2, R79.2, R80.2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
/PCQ0: D11.1 (A), U44.14 (Q0), U46.2 (I0a), U47.2 (I0a)
/PCQ1: D11.2 (A), U44.13 (Q1), U46.4 (I1a), U47.4 (I1a)
/PCQ2: D11.3 (A), U44.12 (Q2), U46.6 (I2a), U47.6 (I2a)
/PCQ3: D11.4 (A), U44.11 (Q3), U46.8 (I3a), U47.8 (I3a)
/PCQ4: D11.5 (A), U45.14 (Q0), U46.11 (I0b), U47.11 (I0b)
/PCQ5: D11.6 (A), U45.13 (Q1), U46.13 (I1b), U47.13 (I1b)
/PCQ6: D11.7 (A), U45.12 (Q2), U46.15 (I2b), U47.15 (I2b)
/PCQ7: D11.8 (A), U45.11 (Q3), U46.17 (I3b), U47.17 (I3b)
/PCQ8: D12.1 (A), U48.14 (Q0), U50.2 (I0a), U51.2 (I0a)
/PCQ9: D12.2 (A), U48.13 (Q1), U50.4 (I1a), U51.4 (I1a)
/PCQ10: D12.3 (A), U48.12 (Q2), U50.6 (I2a), U51.6 (I2a)
/PCQ11: D12.4 (A), U48.11 (Q3), U50.8 (I3a), U51.8 (I3a)
/PCQ12: D12.5 (A), U49.14 (Q0), U50.11 (I0b), U51.11 (I0b)
/PCQ13: D12.6 (A), U49.13 (Q1), U50.13 (I1b), U51.13 (I1b)
/PCQ14: D12.7 (A), U49.12 (Q2), U50.15 (I2b), U51.15 (I2b)
/PCQ15: D12.8 (A), U49.11 (Q3), U50.17 (I3b), U51.17 (I3b)
/PF-WE: U36.4, U37.11 (Cp)
/PF-Wa: U32.12, U36.11, U41.1 (OEa), U41.19 (OEb)
/PF-Wb: J5.18, U36.12
/PbA0: J2.3, U2.18 (O0a), U8.18 (O0a), U14.18 (O0a), U20.18 (O0a), U26.18 (O0a), U38.18 (O0a), U46.18 (O0a), U57.18 (O0a)
/PbA1: J2.4, U2.16 (O1a), U8.16 (O1a), U14.16 (O1a), U20.16 (O1a), U26.16 (O1a), U38.16 (O1a), U46.16 (O1a), U57.16 (O1a)
/PbA2: J2.5, U2.14 (O2a), U8.14 (O2a), U14.14 (O2a), U20.14 (O2a), U26.14 (O2a), U38.14 (O2a), U46.14 (O2a), U57.14 (O2a)
/PbA3: J2.6, U2.12 (O3a), U8.12 (O3a), U14.12 (O3a), U20.12 (O3a), U26.12 (O3a), U38.12 (O3a), U46.12 (O3a), U57.12 (O3a)
/PbA4: J2.7, U2.9 (O0b), U8.9 (O0b), U14.9 (O0b), U20.9 (O0b), U26.9 (O0b), U38.9 (O0b), U46.9 (O0b), U57.9 (O0b)
/PbA5: J2.8, U2.7 (O1b), U8.7 (O1b), U14.7 (O1b), U20.7 (O1b), U26.7 (O1b), U38.7 (O1b), U46.7 (O1b), U57.7 (O1b)
/PbA6: J2.9, U2.5 (O2b), U8.5 (O2b), U14.5 (O2b), U20.5 (O2b), U26.5 (O2b), U38.5 (O2b), U46.5 (O2b), U57.5 (O2b)
/PbA7: J2.10, U2.3 (O3b), U8.3 (O3b), U14.3 (O3b), U20.3 (O3b), U26.3 (O3b), U38.3 (O3b), U46.3 (O3b), U57.3 (O3b)
/PbA8: J2.11, U5.18 (O0a), U11.18 (O0a), U17.18 (O0a), U23.18 (O0a), U29.18 (O0a), U42.18 (O0a), U50.18 (O0a), U58.18 (O0a)
/PbA9: J2.12, U5.16 (O1a), U11.16 (O1a), U17.16 (O1a), U23.16 (O1a), U29.16 (O1a), U42.16 (O1a), U50.16 (O1a), U58.16 (O1a)
/PbA10: J2.13, U5.14 (O2a), U11.14 (O2a), U17.14 (O2a), U23.14 (O2a), U29.14 (O2a), U42.14 (O2a), U50.14 (O2a), U58.14 (O2a)
/PbA11: J2.14, U5.12 (O3a), U11.12 (O3a), U17.12 (O3a), U23.12 (O3a), U29.12 (O3a), U42.12 (O3a), U50.12 (O3a), U58.12 (O3a)
/PbA12: J2.15, U5.9 (O0b), U11.9 (O0b), U17.9 (O0b), U23.9 (O0b), U29.9 (O0b), U42.9 (O0b), U50.9 (O0b), U58.9 (O0b)
/PbA13: J2.16, U5.7 (O1b), U11.7 (O1b), U17.7 (O1b), U23.7 (O1b), U29.7 (O1b), U42.7 (O1b), U50.7 (O1b), U58.7 (O1b)
/PbA14: J2.17, U5.5 (O2b), U11.5 (O2b), U17.5 (O2b), U23.5 (O2b), U29.5 (O2b), U42.5 (O2b), U50.5 (O2b), U58.5 (O2b)
/PbA15: J2.18, U5.3 (O3b), U11.3 (O3b), U17.3 (O3b), U23.3 (O3b), U29.3 (O3b), U42.3 (O3b), U50.3 (O3b), U58.3 (O3b)
/PbB0: J3.3, U3.18 (O0a), U9.18 (O0a), U15.18 (O0a), U21.18 (O0a), U27.18 (O0a), U39.18 (O0a), U47.18 (O0a), U59.18 (O0a)
/PbB1: J3.4, U3.16 (O1a), U9.16 (O1a), U15.16 (O1a), U21.16 (O1a), U27.16 (O1a), U39.16 (O1a), U47.16 (O1a), U59.16 (O1a)
/PbB2: J3.5, U3.14 (O2a), U9.14 (O2a), U15.14 (O2a), U21.14 (O2a), U27.14 (O2a), U39.14 (O2a), U47.14 (O2a), U59.14 (O2a)
/PbB3: J3.6, U3.12 (O3a), U9.12 (O3a), U15.12 (O3a), U21.12 (O3a), U27.12 (O3a), U39.12 (O3a), U47.12 (O3a), U59.12 (O3a)
/PbB4: J3.7, U3.9 (O0b), U9.9 (O0b), U15.9 (O0b), U21.9 (O0b), U27.9 (O0b), U39.9 (O0b), U47.9 (O0b), U59.9 (O0b)
/PbB5: J3.8, U3.7 (O1b), U9.7 (O1b), U15.7 (O1b), U21.7 (O1b), U27.7 (O1b), U39.7 (O1b), U47.7 (O1b), U59.7 (O1b)
/PbB6: J3.9, U3.5 (O2b), U9.5 (O2b), U15.5 (O2b), U21.5 (O2b), U27.5 (O2b), U39.5 (O2b), U47.5 (O2b), U59.5 (O2b)
/PbB7: J3.10, U3.3 (O3b), U9.3 (O3b), U15.3 (O3b), U21.3 (O3b), U27.3 (O3b), U39.3 (O3b), U47.3 (O3b), U59.3 (O3b)
/PbB8: J3.11, U6.18 (O0a), U12.18 (O0a), U18.18 (O0a), U24.18 (O0a), U30.18 (O0a), U43.18 (O0a), U51.18 (O0a), U60.18 (O0a)
/PbB9: J3.12, U6.16 (O1a), U12.16 (O1a), U18.16 (O1a), U24.16 (O1a), U30.16 (O1a), U43.16 (O1a), U51.16 (O1a), U60.16 (O1a)
/PbB10: J3.13, U6.14 (O2a), U12.14 (O2a), U18.14 (O2a), U24.14 (O2a), U30.14 (O2a), U43.14 (O2a), U51.14 (O2a), U60.14 (O2a)
/PbB11: J3.14, U6.12 (O3a), U12.12 (O3a), U18.12 (O3a), U24.12 (O3a), U30.12 (O3a), U43.12 (O3a), U51.12 (O3a), U60.12 (O3a)
/PbB12: J3.15, U6.9 (O0b), U12.9 (O0b), U18.9 (O0b), U24.9 (O0b), U30.9 (O0b), U43.9 (O0b), U51.9 (O0b), U60.9 (O0b)
/PbB13: J3.16, U6.7 (O1b), U12.7 (O1b), U18.7 (O1b), U24.7 (O1b), U30.7 (O1b), U43.7 (O1b), U51.7 (O1b), U60.7 (O1b)
/PbB14: J3.17, U6.5 (O2b), U12.5 (O2b), U18.5 (O2b), U24.5 (O2b), U30.5 (O2b), U43.5 (O2b), U51.5 (O2b), U60.5 (O2b)
/PbB15: J3.18, U6.3 (O3b), U12.3 (O3b), U18.3 (O3b), U24.3 (O3b), U30.3 (O3b), U43.3 (O3b), U51.3 (O3b), U60.3 (O3b)
/QExFl: D17.5 (A), J6.15, U37.12 (Q4), U41.11 (I0b), U42.11 (I0b), U43.11 (I0b)
/QIRQ: D17.2 (A), J6.4, U37.5 (Q1), U38.4 (I1a), U39.4 (I1a), U41.4 (I1a)
/QIntProg: D17.4 (A), J6.6, U37.9 (Q3), U38.8 (I3a), U39.8 (I3a), U41.8 (I3a)
/QIntSw: D17.3 (A), J6.5, U37.6 (Q2), U38.6 (I2a), U39.6 (I2a), U41.6 (I2a)
/QNMI: D17.1 (A), J6.3, U37.2 (Q0), U38.2 (I0a), U39.2 (I0a), U41.2 (I0a)
/QSCout: D17.8 (A), J6.18, U37.19 (Q7), U42.17 (I3b), U43.17 (I3b)
/QUCout: D17.7 (A), J6.17, U37.16 (Q6), U42.15 (I2b), U43.15 (I2b)
/QZero: D17.6 (A), J6.16, U37.15 (Q5), U42.13 (I1b), U43.13 (I1b)
/R0-WE: U1.11 (Cp), U4.11 (Cp), U35.1
/R0Q0: D1.1 (A), U1.2 (Q0), U2.2 (I0a), U3.2 (I0a)
/R0Q1: D1.2 (A), U1.5 (Q1), U2.4 (I1a), U3.4 (I1a)
/R0Q2: D1.3 (A), U1.6 (Q2), U2.6 (I2a), U3.6 (I2a)
/R0Q3: D1.4 (A), U1.9 (Q3), U2.8 (I3a), U3.8 (I3a)
/R0Q4: D1.5 (A), U1.12 (Q4), U2.11 (I0b), U3.11 (I0b)
/R0Q5: D1.6 (A), U1.15 (Q5), U2.13 (I1b), U3.13 (I1b)
/R0Q6: D1.7 (A), U1.16 (Q6), U2.15 (I2b), U3.15 (I2b)
/R0Q7: D1.8 (A), U1.19 (Q7), U2.17 (I3b), U3.17 (I3b)
/R0Q8: D2.1 (A), U4.2 (Q0), U5.2 (I0a), U6.2 (I0a)
/R0Q9: D2.2 (A), U4.5 (Q1), U5.4 (I1a), U6.4 (I1a)
/R0Q10: D2.3 (A), U4.6 (Q2), U5.6 (I2a), U6.6 (I2a)
/R0Q11: D2.4 (A), U4.9 (Q3), U5.8 (I3a), U6.8 (I3a)
/R0Q12: D2.5 (A), U4.12 (Q4), U5.11 (I0b), U6.11 (I0b)
/R0Q13: D2.6 (A), U4.15 (Q5), U5.13 (I1b), U6.13 (I1b)
/R0Q14: D2.7 (A), U4.16 (Q6), U5.15 (I2b), U6.15 (I2b)
/R0Q15: D2.8 (A), U4.19 (Q7), U5.17 (I3b), U6.17 (I3b)
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

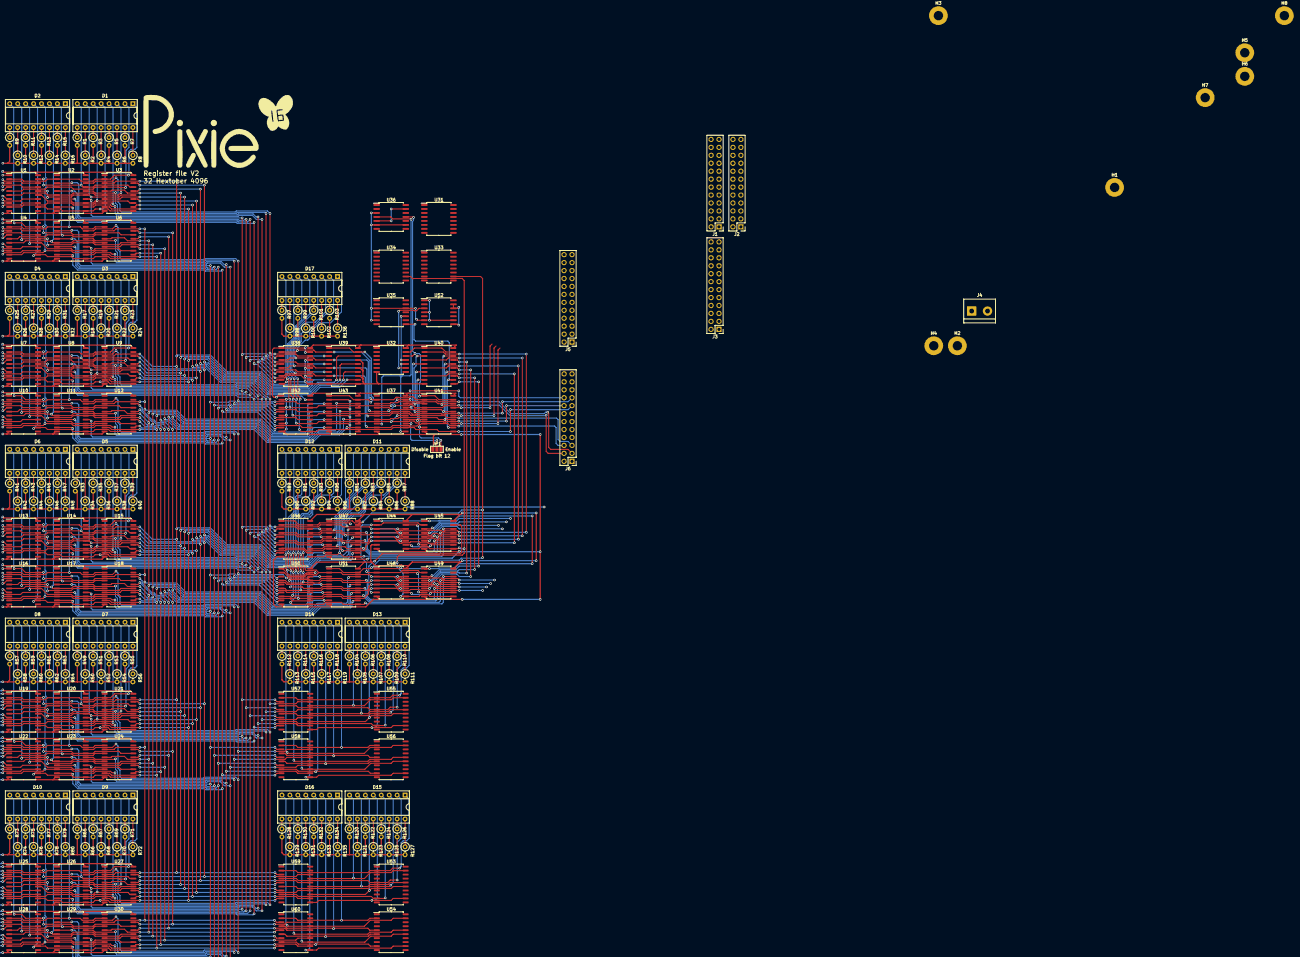
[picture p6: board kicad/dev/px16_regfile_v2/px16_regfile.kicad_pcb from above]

Board: 2 copper layers, 228 parts (0 on the bottom side), 396 nets.

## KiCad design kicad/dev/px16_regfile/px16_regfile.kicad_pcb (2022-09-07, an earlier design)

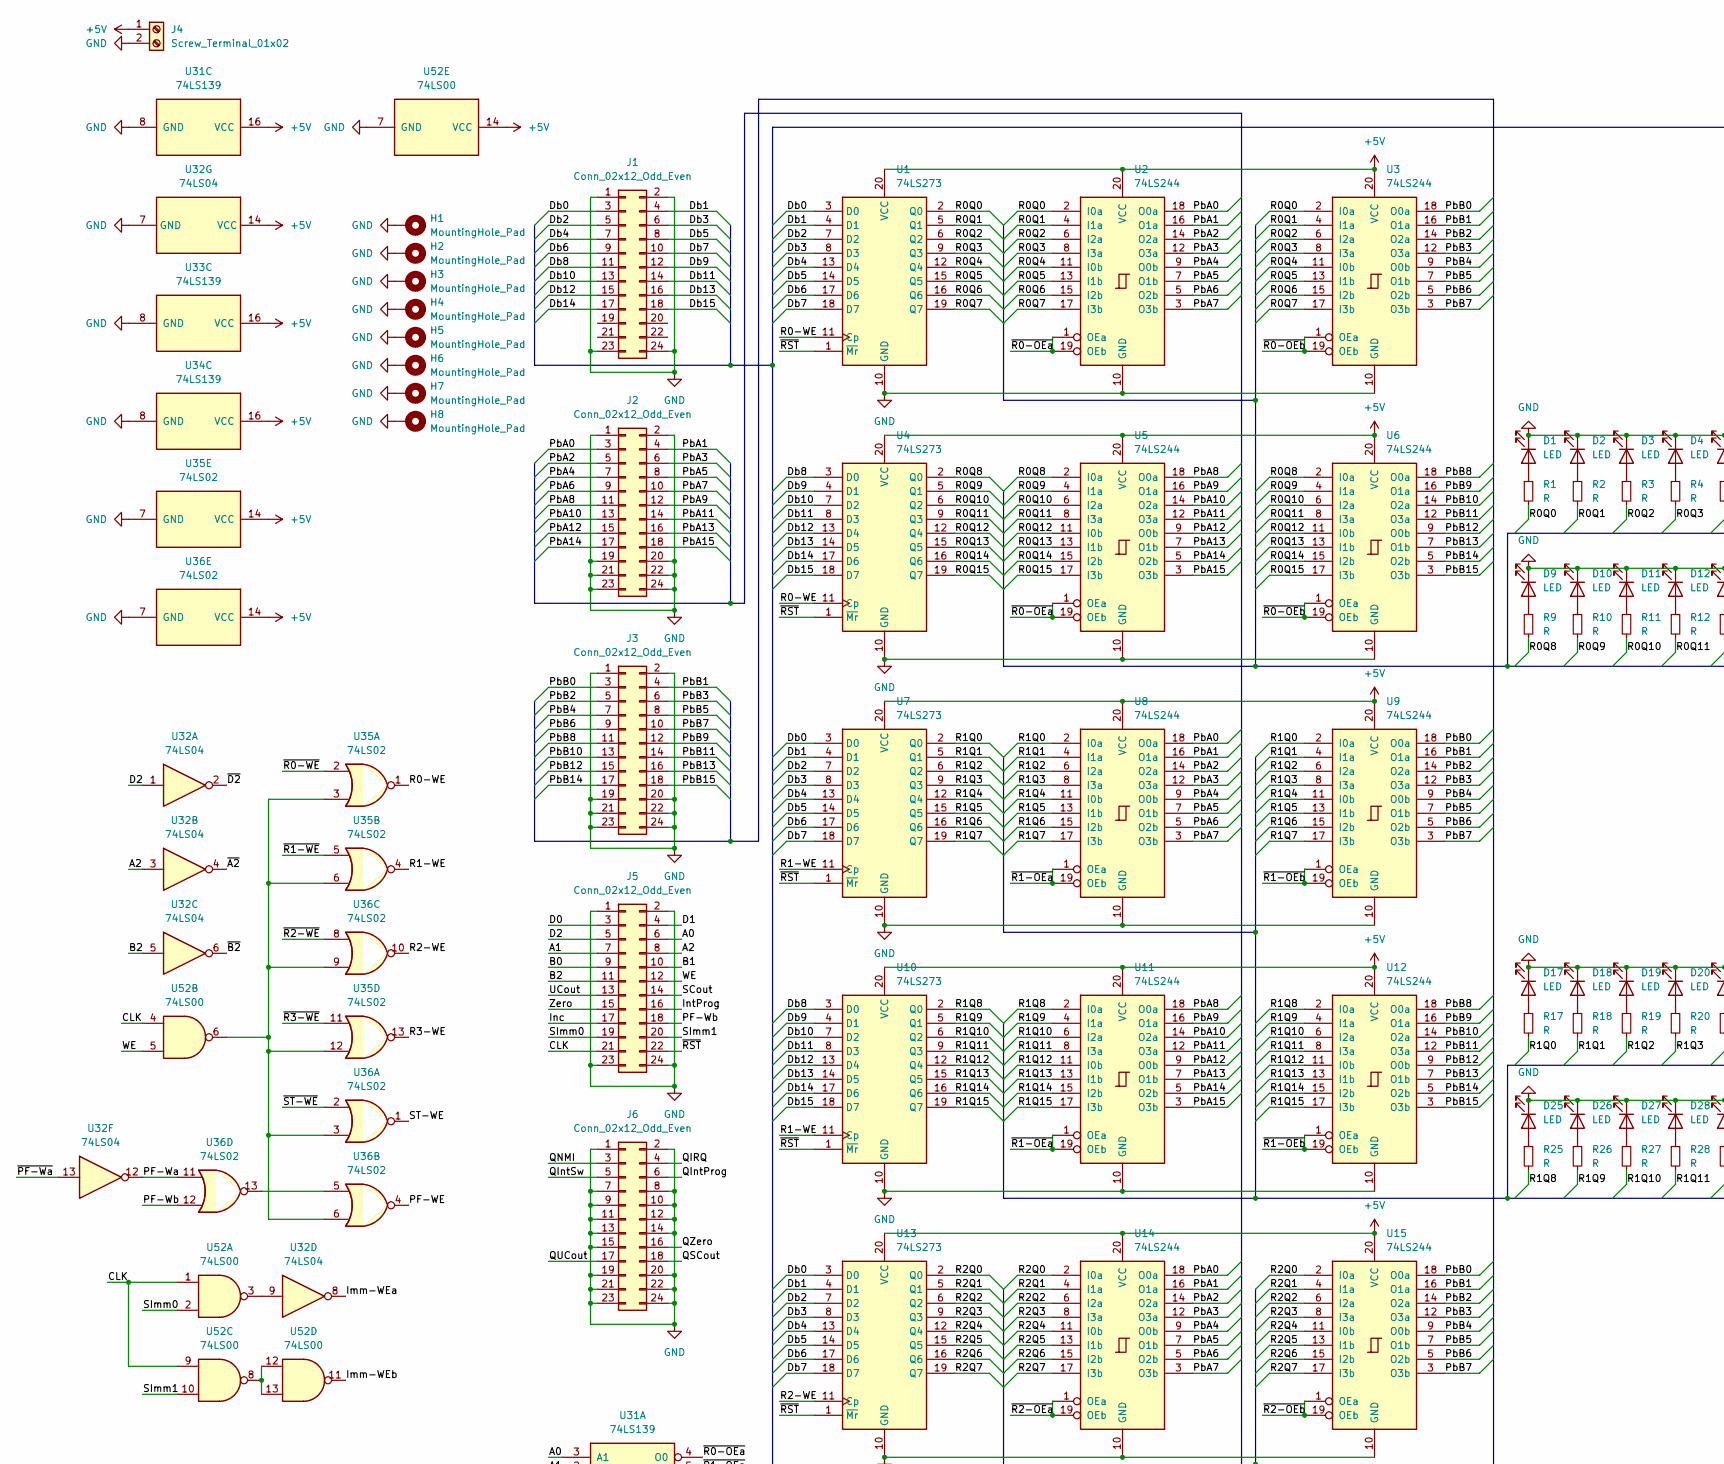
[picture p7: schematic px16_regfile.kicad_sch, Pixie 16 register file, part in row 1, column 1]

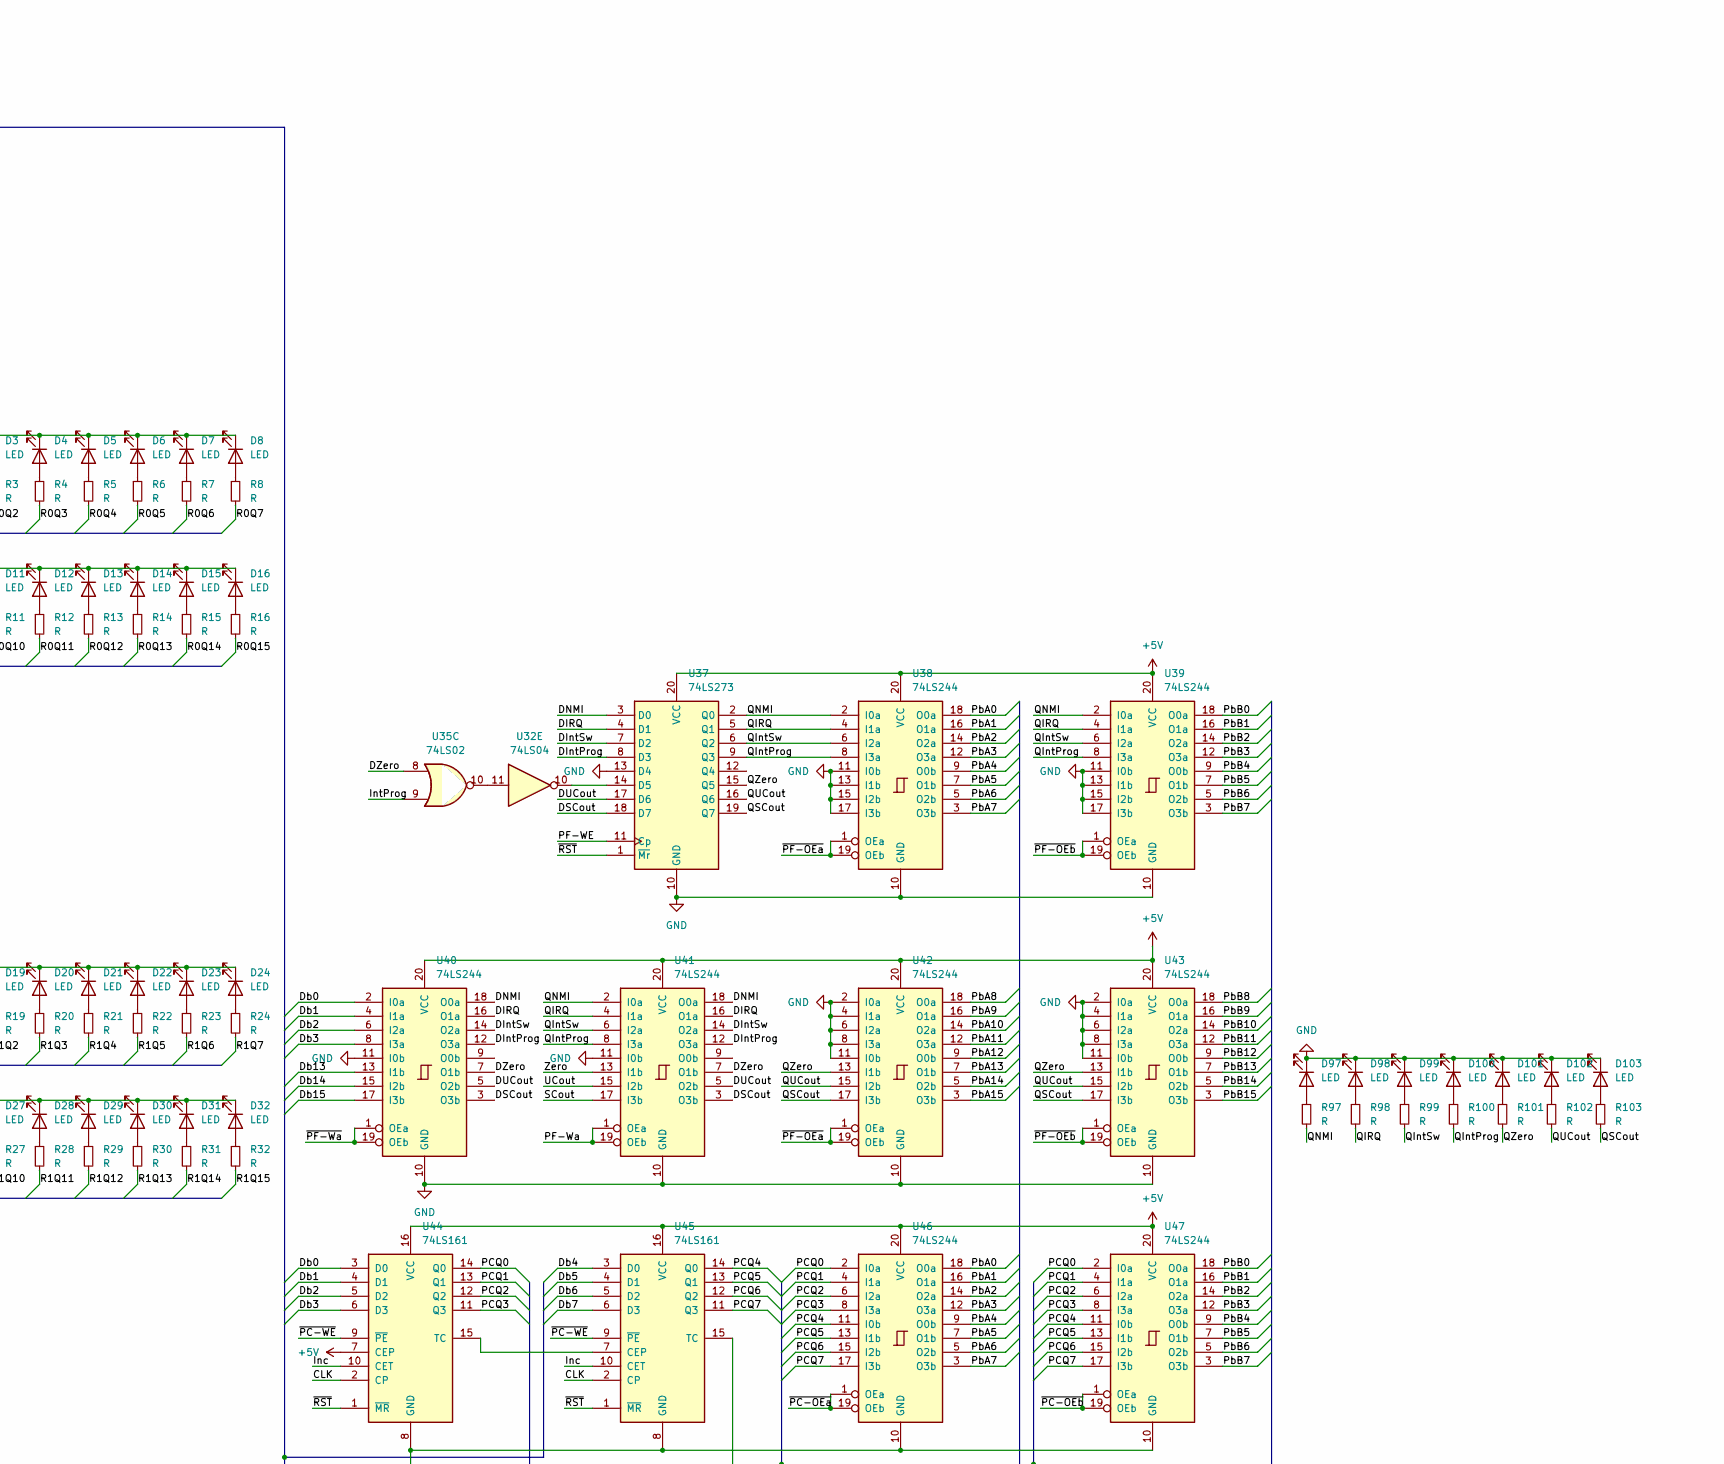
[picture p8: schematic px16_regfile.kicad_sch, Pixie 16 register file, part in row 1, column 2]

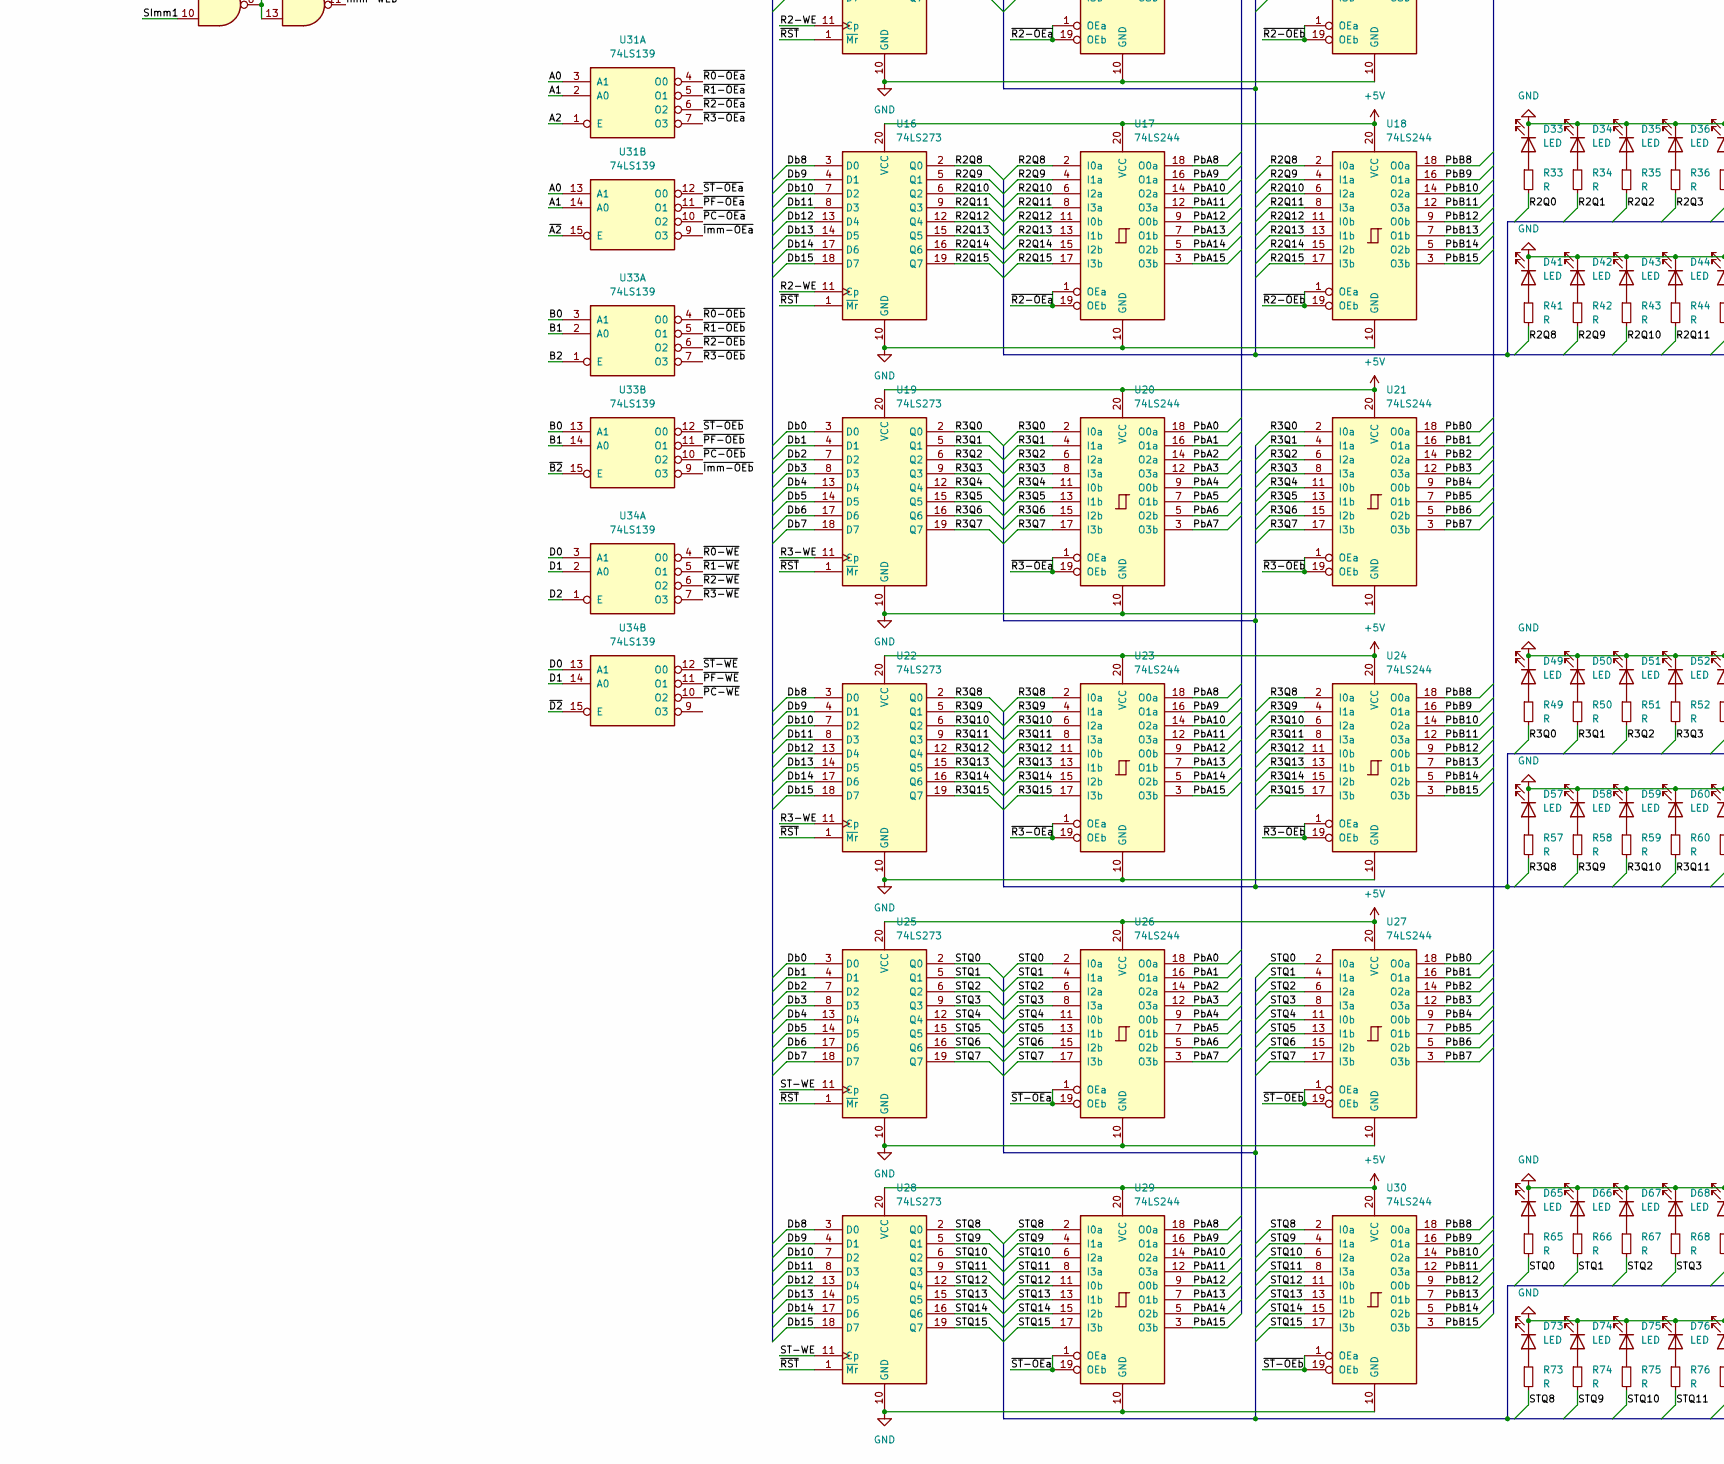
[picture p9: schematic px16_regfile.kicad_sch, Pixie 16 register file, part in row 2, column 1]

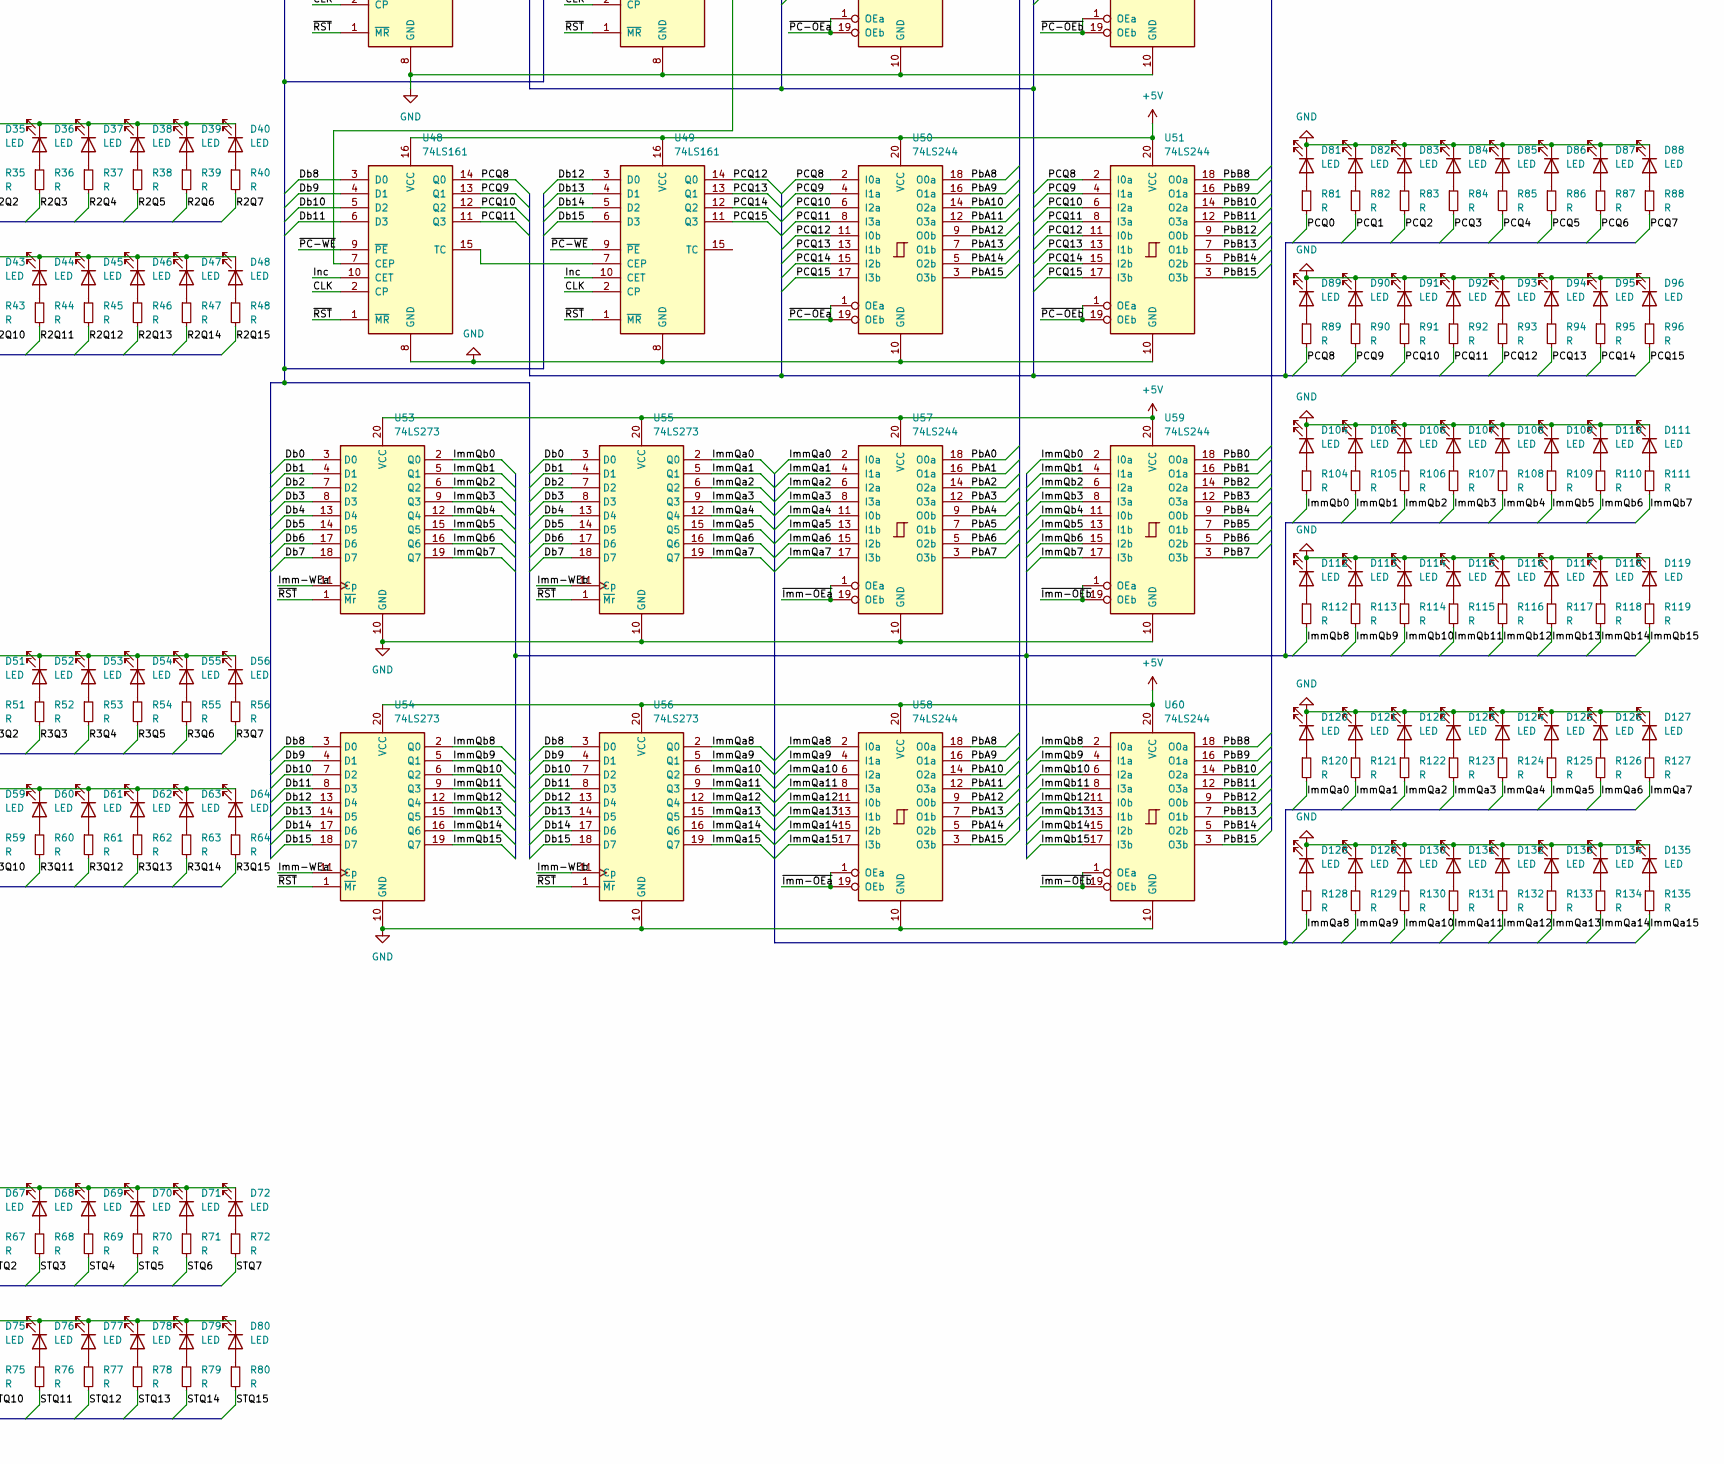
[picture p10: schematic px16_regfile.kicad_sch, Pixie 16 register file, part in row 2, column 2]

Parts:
D1, D2, D3, D4, D5, D6, D7, D8, D9, D10, D11, D12, D13, D14, D15, D16, D17, D18, D19, D20, D21, D22, D23, D24, D25, D26, D27, D28, D29, D30, D31, D32, D33, D34, D35, D36, D37, D38, D39, D40, D41, D42, D43, D44, D45, D46, D47, D48, D49, D50, D51, D52, D53, D54, D55, D56, D57, D58, D59, D60, D61, D62, D63, D64, D65, D66, D67, D68, D69, D70, D71, D72, D73, D74, D75, D76, D77, D78, D79, D80, D81, D82, D83, D84, D85, D86, D87, D88, D89, D90, D91, D92, D93, D94, D95, D96, D97, D98, D99, D100, D101, D102, D103, D104, D105, D106, D107, D108, D109, D110, D111, D112, D113, D114, D115, D116, D117, D118, D119, D120, D121, D122, D123, D124, D125, D126, D127, D128, D129, D130, D131, D132, D133, D134, D135: LED; LED_D5.0mm
H1: MountingHole_Pad
H2, H3, H4, H5, H6, H7, H8: MountingHole_Pad; MountingHole_3mm_Pad
J1, J2, J3, J5, J6: Conn_02x12_Odd_Even; PinHeader_2x12_P2.54mm_Vertical
J4: Screw_Terminal_01x02; TerminalBlock_bornier-2_P5.08mm
R1, R2, R3, R4, R5, R6, R7, R8, R9, R10, R11, R12, R13, R14, R15, R16, R17, R18, R19, R20, R21, R22, R23, R24, R25, R26, R27, R28, R29, R30, R31, R32, R33, R34, R35, R36, R37, R38, R39, R40, R41, R42, R43, R44, R45, R46, R47, R48, R49, R50, R51, R52, R53, R54, R55, R56, R57, R58, R59, R60, R61, R62, R63, R64, R65, R66, R67, R68, R69, R70, R71, R72, R73, R74, R75, R76, R77, R78, R79, R80, R81, R82, R83, R84, R85, R86, R87, R88, R89, R90, R91, R92, R93, R94, R95, R96, R97, R98, R99, R100, R101, R102, R103, R104, R105, R106, R107, R108, R109, R110, R111, R112, R113, R114, R115, R116, R117, R118, R119, R120, R121, R122, R123, R124, R125, R126, R127, R128, R129, R130, R131, R132, R133, R134, R135: R; R_Axial_DIN0207_L6.3mm_D2.5mm_P2.54mm_Vertical
U1, U4, U7, U10, U13, U16, U19, U22, U25, U28, U37, U53, U54, U55, U56: 74LS273; DIP-20_W7.62mm
U2, U3, U5, U6, U8, U9, U11, U12, U14, U15, U17, U18, U20, U21, U23, U24, U26, U27, U29, U30, U38, U39, U40, U41, U42, U43, U46, U47, U50, U51, U57, U58, U59, U60: 74LS244; DIP-20_W7.62mm
U31, U33, U34: 74LS139; DIP-16_W7.62mm
U32: 74LS04; DIP-14_W7.62mm
U35, U36: 74LS02; DIP-14_W7.62mm
U44, U45, U48, U49: 74LS161; DIP-16_W7.62mm
U52: 74LS00; DIP-14_W7.62mm

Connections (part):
+5V: J4.1, U1.20 (VCC), U2.20 (VCC), U3.20 (VCC), U4.20 (VCC), U5.20 (VCC), U6.20 (VCC), U7.20 (VCC), U8.20 (VCC), U9.20 (VCC), U10.20 (VCC), U11.20 (VCC), U12.20 (VCC), U13.20 (VCC), U14.20 (VCC), U15.20 (VCC), U16.20 (VCC), U17.20 (VCC), U18.20 (VCC), U19.20 (VCC), U20.20 (VCC), U21.20 (VCC), U22.20 (VCC), U23.20 (VCC), U24.20 (VCC), U25.20 (VCC), U26.20 (VCC), U27.20 (VCC), U28.20 (VCC), U29.20 (VCC), U30.20 (VCC), U31.16 (VCC), U32.14 (VCC), U33.16 (VCC), U34.16 (VCC), U35.14 (VCC), U36.14 (VCC), U37.20 (VCC), U38.20 (VCC), U39.20 (VCC), U40.20 (VCC), U41.20 (VCC), U42.20 (VCC), U43.20 (VCC), U44.7 (CEP), U44.16 (VCC), U45.16 (VCC), U46.20 (VCC), U47.20 (VCC), U48.16 (VCC), U49.16 (VCC), U50.20 (VCC), U51.20 (VCC), U52.14 (VCC), U53.20 (VCC), U54.20 (VCC), U55.20 (VCC), U56.20 (VCC), U57.20 (VCC), U58.20 (VCC), U59.20 (VCC), U60.20 (VCC)
/A0: J5.6, U31.3 (A1), U31.13 (A1)
/A1: J5.7, U31.2 (A0), U31.14 (A0)
/A2: J5.8, U31.1 (E), U32.3
/B0: J5.9, U33.3 (A1), U33.13 (A1)
/B1: J5.10, U33.2 (A0), U33.14 (A0)
/B2: J5.11, U32.5, U33.1 (E)
/CLK: J5.21, U44.2 (CP), U45.2 (CP), U48.2 (CP), U49.2 (CP), U52.1, U52.4, U52.9
/D0: J5.3, U34.3 (A1), U34.13 (A1)
/D1: J5.4, U34.2 (A0), U34.14 (A0)
/D2: J5.5, U32.1, U34.1 (E)
/DIRQ: U37.4 (D1), U40.16 (O1a), U41.16 (O1a)
/DIntProg: U37.8 (D3), U40.12 (O3a), U41.12 (O3a)
/DIntSw: U37.7 (D2), U40.14 (O2a), U41.14 (O2a)
/DNMI: U37.3 (D0), U40.18 (O0a), U41.18 (O0a)
/DSCout: U37.18 (D7), U40.3 (O3b), U41.3 (O3b)
/DUCout: U37.17 (D6), U40.5 (O2b), U41.5 (O2b)
/DZero: U35.8, U40.7 (O1b), U41.7 (O1b)
/Db0: J1.3, U1.3 (D0), U7.3 (D0), U13.3 (D0), U19.3 (D0), U25.3 (D0), U40.2 (I0a), U44.3 (D0), U53.3 (D0), U55.3 (D0)
/Db1: J1.4, U1.4 (D1), U7.4 (D1), U13.4 (D1), U19.4 (D1), U25.4 (D1), U40.4 (I1a), U44.4 (D1), U53.4 (D1), U55.4 (D1)
/Db2: J1.5, U1.7 (D2), U7.7 (D2), U13.7 (D2), U19.7 (D2), U25.7 (D2), U40.6 (I2a), U44.5 (D2), U53.7 (D2), U55.7 (D2)
/Db3: J1.6, U1.8 (D3), U7.8 (D3), U13.8 (D3), U19.8 (D3), U25.8 (D3), U40.8 (I3a), U44.6 (D3), U53.8 (D3), U55.8 (D3)
/Db4: J1.7, U1.13 (D4), U7.13 (D4), U13.13 (D4), U19.13 (D4), U25.13 (D4), U45.3 (D0), U53.13 (D4), U55.13 (D4)
/Db5: J1.8, U1.14 (D5), U7.14 (D5), U13.14 (D5), U19.14 (D5), U25.14 (D5), U45.4 (D1), U53.14 (D5), U55.14 (D5)
/Db6: J1.9, U1.17 (D6), U7.17 (D6), U13.17 (D6), U19.17 (D6), U25.17 (D6), U45.5 (D2), U53.17 (D6), U55.17 (D6)
/Db7: J1.10, U1.18 (D7), U7.18 (D7), U13.18 (D7), U19.18 (D7), U25.18 (D7), U45.6 (D3), U53.18 (D7), U55.18 (D7)
/Db8: J1.11, U4.3 (D0), U10.3 (D0), U16.3 (D0), U22.3 (D0), U28.3 (D0), U48.3 (D0), U54.3 (D0), U56.3 (D0)
/Db9: J1.12, U4.4 (D1), U10.4 (D1), U16.4 (D1), U22.4 (D1), U28.4 (D1), U48.4 (D1), U54.4 (D1), U56.4 (D1)
/Db10: J1.13, U4.7 (D2), U10.7 (D2), U16.7 (D2), U22.7 (D2), U28.7 (D2), U48.5 (D2), U54.7 (D2), U56.7 (D2)
/Db11: J1.14, U4.8 (D3), U10.8 (D3), U16.8 (D3), U22.8 (D3), U28.8 (D3), U48.6 (D3), U54.8 (D3), U56.8 (D3)
/Db12: J1.15, U4.13 (D4), U10.13 (D4), U16.13 (D4), U22.13 (D4), U28.13 (D4), U49.3 (D0), U54.13 (D4), U56.13 (D4)
/Db13: J1.16, U4.14 (D5), U10.14 (D5), U16.14 (D5), U22.14 (D5), U28.14 (D5), U40.13 (I1b), U49.4 (D1), U54.14 (D5), U56.14 (D5)
/Db14: J1.17, U4.17 (D6), U10.17 (D6), U16.17 (D6), U22.17 (D6), U28.17 (D6), U40.15 (I2b), U49.5 (D2), U54.17 (D6), U56.17 (D6)
/Db15: J1.18, U4.18 (D7), U10.18 (D7), U16.18 (D7), U22.18 (D7), U28.18 (D7), U40.17 (I3b), U49.6 (D3), U54.18 (D7), U56.18 (D7)
/Imm-WEa: U32.8, U53.11 (Cp), U54.11 (Cp)
/Imm-WEb: U52.11, U55.11 (Cp), U56.11 (Cp)
/ImmQa0: R120.2, U55.2 (Q0), U57.2 (I0a)
/ImmQa1: R121.2, U55.5 (Q1), U57.4 (I1a)
/ImmQa2: R122.2, U55.6 (Q2), U57.6 (I2a)
/ImmQa3: R123.2, U55.9 (Q3), U57.8 (I3a)
/ImmQa4: R124.2, U55.12 (Q4), U57.11 (I0b)
/ImmQa5: R125.2, U55.15 (Q5), U57.13 (I1b)
/ImmQa6: R126.2, U55.16 (Q6), U57.15 (I2b)
/ImmQa7: R127.2, U55.19 (Q7), U57.17 (I3b)
/ImmQa8: R128.2, U56.2 (Q0), U58.2 (I0a)
/ImmQa9: R129.2, U56.5 (Q1), U58.4 (I1a)
/ImmQa10: R130.2, U56.6 (Q2), U58.6 (I2a)
/ImmQa11: R131.2, U56.9 (Q3), U58.8 (I3a)
/ImmQa12: R132.2, U56.12 (Q4), U58.11 (I0b)
/ImmQa13: R133.2, U56.15 (Q5), U58.13 (I1b)
/ImmQa14: R134.2, U56.16 (Q6), U58.15 (I2b)
/ImmQa15: R135.2, U56.19 (Q7), U58.17 (I3b)
/ImmQb0: R104.2, U53.2 (Q0), U59.2 (I0a)
/ImmQb1: R105.2, U53.5 (Q1), U59.4 (I1a)
/ImmQb2: R106.2, U53.6 (Q2), U59.6 (I2a)
/ImmQb3: R107.2, U53.9 (Q3), U59.8 (I3a)
/ImmQb4: R108.2, U53.12 (Q4), U59.11 (I0b)
/ImmQb5: R109.2, U53.15 (Q5), U59.13 (I1b)
/ImmQb6: R110.2, U53.16 (Q6), U59.15 (I2b)
/ImmQb7: R111.2, U53.19 (Q7), U59.17 (I3b)
/ImmQb8: R112.2, U54.2 (Q0), U60.2 (I0a)
/ImmQb9: R113.2, U54.5 (Q1), U60.4 (I1a)
/ImmQb10: R114.2, U54.6 (Q2), U60.6 (I2a)
/ImmQb11: R115.2, U54.9 (Q3), U60.8 (I3a)
/ImmQb12: R116.2, U54.12 (Q4), U60.11 (I0b)
/ImmQb13: R117.2, U54.15 (Q5), U60.13 (I1b)
/ImmQb14: R118.2, U54.16 (Q6), U60.15 (I2b)
/ImmQb15: R119.2, U54.19 (Q7), U60.17 (I3b)
/Inc: J5.17, U44.10 (CET), U45.10 (CET), U48.10 (CET), U49.10 (CET)
/IntProg: J5.16, U35.9
/PCQ0: R81.2, U44.14 (Q0), U46.2 (I0a), U47.2 (I0a)
/PCQ1: R82.2, U44.13 (Q1), U46.4 (I1a), U47.4 (I1a)
/PCQ2: R83.2, U44.12 (Q2), U46.6 (I2a), U47.6 (I2a)
/PCQ3: R84.2, U44.11 (Q3), U46.8 (I3a), U47.8 (I3a)
/PCQ4: R85.2, U45.14 (Q0), U46.11 (I0b), U47.11 (I0b)
/PCQ5: R86.2, U45.13 (Q1), U46.13 (I1b), U47.13 (I1b)
/PCQ6: R87.2, U45.12 (Q2), U46.15 (I2b), U47.15 (I2b)
/PCQ7: R88.2, U45.11 (Q3), U46.17 (I3b), U47.17 (I3b)
/PCQ8: R89.2, U48.14 (Q0), U50.2 (I0a), U51.2 (I0a)
/PCQ9: R90.2, U48.13 (Q1), U50.4 (I1a), U51.4 (I1a)
/PCQ10: R91.2, U48.12 (Q2), U50.6 (I2a), U51.6 (I2a)
/PCQ11: R92.2, U48.11 (Q3), U50.8 (I3a), U51.8 (I3a)
/PCQ12: R93.2, U49.14 (Q0), U50.11 (I0b), U51.11 (I0b)
/PCQ13: R94.2, U49.13 (Q1), U50.13 (I1b), U51.13 (I1b)
/PCQ14: R95.2, U49.12 (Q2), U50.15 (I2b), U51.15 (I2b)
/PCQ15: R96.2, U49.11 (Q3), U50.17 (I3b), U51.17 (I3b)
/PF-WE: U36.4, U37.11 (Cp)
/PF-Wa: U32.12, U36.11, U41.1 (OEa), U41.19 (OEb)
/PF-Wb: J5.18, U36.12
/PbA0: J2.3, U2.18 (O0a), U8.18 (O0a), U14.18 (O0a), U20.18 (O0a), U26.18 (O0a), U38.18 (O0a), U46.18 (O0a), U57.18 (O0a)
/PbA1: J2.4, U2.16 (O1a), U8.16 (O1a), U14.16 (O1a), U20.16 (O1a), U26.16 (O1a), U38.16 (O1a), U46.16 (O1a), U57.16 (O1a)
/PbA2: J2.5, U2.14 (O2a), U8.14 (O2a), U14.14 (O2a), U20.14 (O2a), U26.14 (O2a), U38.14 (O2a), U46.14 (O2a), U57.14 (O2a)
/PbA3: J2.6, U2.12 (O3a), U8.12 (O3a), U14.12 (O3a), U20.12 (O3a), U26.12 (O3a), U38.12 (O3a), U46.12 (O3a), U57.12 (O3a)
/PbA4: J2.7, U2.9 (O0b), U8.9 (O0b), U14.9 (O0b), U20.9 (O0b), U26.9 (O0b), U38.9 (O0b), U46.9 (O0b), U57.9 (O0b)
/PbA5: J2.8, U2.7 (O1b), U8.7 (O1b), U14.7 (O1b), U20.7 (O1b), U26.7 (O1b), U38.7 (O1b), U46.7 (O1b), U57.7 (O1b)
/PbA6: J2.9, U2.5 (O2b), U8.5 (O2b), U14.5 (O2b), U20.5 (O2b), U26.5 (O2b), U38.5 (O2b), U46.5 (O2b), U57.5 (O2b)
/PbA7: J2.10, U2.3 (O3b), U8.3 (O3b), U14.3 (O3b), U20.3 (O3b), U26.3 (O3b), U38.3 (O3b), U46.3 (O3b), U57.3 (O3b)
/PbA8: J2.11, U5.18 (O0a), U11.18 (O0a), U17.18 (O0a), U23.18 (O0a), U29.18 (O0a), U42.18 (O0a), U50.18 (O0a), U58.18 (O0a)
/PbA9: J2.12, U5.16 (O1a), U11.16 (O1a), U17.16 (O1a), U23.16 (O1a), U29.16 (O1a), U42.16 (O1a), U50.16 (O1a), U58.16 (O1a)
/PbA10: J2.13, U5.14 (O2a), U11.14 (O2a), U17.14 (O2a), U23.14 (O2a), U29.14 (O2a), U42.14 (O2a), U50.14 (O2a), U58.14 (O2a)
/PbA11: J2.14, U5.12 (O3a), U11.12 (O3a), U17.12 (O3a), U23.12 (O3a), U29.12 (O3a), U42.12 (O3a), U50.12 (O3a), U58.12 (O3a)
/PbA12: J2.15, U5.9 (O0b), U11.9 (O0b), U17.9 (O0b), U23.9 (O0b), U29.9 (O0b), U42.9 (O0b), U50.9 (O0b), U58.9 (O0b)
/PbA13: J2.16, U5.7 (O1b), U11.7 (O1b), U17.7 (O1b), U23.7 (O1b), U29.7 (O1b), U42.7 (O1b), U50.7 (O1b), U58.7 (O1b)
/PbA14: J2.17, U5.5 (O2b), U11.5 (O2b), U17.5 (O2b), U23.5 (O2b), U29.5 (O2b), U42.5 (O2b), U50.5 (O2b), U58.5 (O2b)
/PbA15: J2.18, U5.3 (O3b), U11.3 (O3b), U17.3 (O3b), U23.3 (O3b), U29.3 (O3b), U42.3 (O3b), U50.3 (O3b), U58.3 (O3b)
/PbB0: J3.3, U3.18 (O0a), U9.18 (O0a), U15.18 (O0a), U21.18 (O0a), U27.18 (O0a), U39.18 (O0a), U47.18 (O0a), U59.18 (O0a)
/PbB1: J3.4, U3.16 (O1a), U9.16 (O1a), U15.16 (O1a), U21.16 (O1a), U27.16 (O1a), U39.16 (O1a), U47.16 (O1a), U59.16 (O1a)
/PbB2: J3.5, U3.14 (O2a), U9.14 (O2a), U15.14 (O2a), U21.14 (O2a), U27.14 (O2a), U39.14 (O2a), U47.14 (O2a), U59.14 (O2a)
/PbB3: J3.6, U3.12 (O3a), U9.12 (O3a), U15.12 (O3a), U21.12 (O3a), U27.12 (O3a), U39.12 (O3a), U47.12 (O3a), U59.12 (O3a)
/PbB4: J3.7, U3.9 (O0b), U9.9 (O0b), U15.9 (O0b), U21.9 (O0b), U27.9 (O0b), U39.9 (O0b), U47.9 (O0b), U59.9 (O0b)
/PbB5: J3.8, U3.7 (O1b), U9.7 (O1b), U15.7 (O1b), U21.7 (O1b), U27.7 (O1b), U39.7 (O1b), U47.7 (O1b), U59.7 (O1b)
/PbB6: J3.9, U3.5 (O2b), U9.5 (O2b), U15.5 (O2b), U21.5 (O2b), U27.5 (O2b), U39.5 (O2b), U47.5 (O2b), U59.5 (O2b)
/PbB7: J3.10, U3.3 (O3b), U9.3 (O3b), U15.3 (O3b), U21.3 (O3b), U27.3 (O3b), U39.3 (O3b), U47.3 (O3b), U59.3 (O3b)
/PbB8: J3.11, U6.18 (O0a), U12.18 (O0a), U18.18 (O0a), U24.18 (O0a), U30.18 (O0a), U43.18 (O0a), U51.18 (O0a), U60.18 (O0a)
/PbB9: J3.12, U6.16 (O1a), U12.16 (O1a), U18.16 (O1a), U24.16 (O1a), U30.16 (O1a), U43.16 (O1a), U51.16 (O1a), U60.16 (O1a)
/PbB10: J3.13, U6.14 (O2a), U12.14 (O2a), U18.14 (O2a), U24.14 (O2a), U30.14 (O2a), U43.14 (O2a), U51.14 (O2a), U60.14 (O2a)
/PbB11: J3.14, U6.12 (O3a), U12.12 (O3a), U18.12 (O3a), U24.12 (O3a), U30.12 (O3a), U43.12 (O3a), U51.12 (O3a), U60.12 (O3a)
/PbB12: J3.15, U6.9 (O0b), U12.9 (O0b), U18.9 (O0b), U24.9 (O0b), U30.9 (O0b), U43.9 (O0b), U51.9 (O0b), U60.9 (O0b)
/PbB13: J3.16, U6.7 (O1b), U12.7 (O1b), U18.7 (O1b), U24.7 (O1b), U30.7 (O1b), U43.7 (O1b), U51.7 (O1b), U60.7 (O1b)
/PbB14: J3.17, U6.5 (O2b), U12.5 (O2b), U18.5 (O2b), U24.5 (O2b), U30.5 (O2b), U43.5 (O2b), U51.5 (O2b), U60.5 (O2b)
/PbB15: J3.18, U6.3 (O3b), U12.3 (O3b), U18.3 (O3b), U24.3 (O3b), U30.3 (O3b), U43.3 (O3b), U51.3 (O3b), U60.3 (O3b)
/QIRQ: J6.4, R98.2, U37.5 (Q1), U38.4 (I1a), U39.4 (I1a), U41.4 (I1a)
/QIntProg: J6.6, R100.2, U37.9 (Q3), U38.8 (I3a), U39.8 (I3a), U41.8 (I3a)
/QIntSw: J6.5, R99.2, U37.6 (Q2), U38.6 (I2a), U39.6 (I2a), U41.6 (I2a)
/QNMI: J6.3, R97.2, U37.2 (Q0), U38.2 (I0a), U39.2 (I0a), U41.2 (I0a)
/QSCout: J6.18, R103.2, U37.19 (Q7), U42.17 (I3b), U43.17 (I3b)
/QUCout: J6.17, R102.2, U37.16 (Q6), U42.15 (I2b), U43.15 (I2b)
/QZero: J6.16, R101.2, U37.15 (Q5), U42.13 (I1b), U43.13 (I1b)
/R0-WE: U1.11 (Cp), U4.11 (Cp), U35.1
/R0Q0: R1.2, U1.2 (Q0), U2.2 (I0a), U3.2 (I0a)
/R0Q1: R2.2, U1.5 (Q1), U2.4 (I1a), U3.4 (I1a)
/R0Q2: R3.2, U1.6 (Q2), U2.6 (I2a), U3.6 (I2a)
/R0Q3: R4.2, U1.9 (Q3), U2.8 (I3a), U3.8 (I3a)
/R0Q4: R5.2, U1.12 (Q4), U2.11 (I0b), U3.11 (I0b)
/R0Q5: R6.2, U1.15 (Q5), U2.13 (I1b), U3.13 (I1b)
/R0Q6: R7.2, U1.16 (Q6), U2.15 (I2b), U3.15 (I2b)
/R0Q7: R8.2, U1.19 (Q7), U2.17 (I3b), U3.17 (I3b)
/R0Q8: R9.2, U4.2 (Q0), U5.2 (I0a), U6.2 (I0a)
/R0Q9: R10.2, U4.5 (Q1), U5.4 (I1a), U6.4 (I1a)
/R0Q10: R11.2, U4.6 (Q2), U5.6 (I2a), U6.6 (I2a)
/R0Q11: R12.2, U4.9 (Q3), U5.8 (I3a), U6.8 (I3a)
/R0Q12: R13.2, U4.12 (Q4), U5.11 (I0b), U6.11 (I0b)
/R0Q13: R14.2, U4.15 (Q5), U5.13 (I1b), U6.13 (I1b)
/R0Q14: R15.2, U4.16 (Q6), U5.15 (I2b), U6.15 (I2b)
/R0Q15: R16.2, U4.19 (Q7), U5.17 (I3b), U6.17 (I3b)
/R1-WE: U7.11 (Cp), U10.11 (Cp), U35.4
/R1Q0: R17.2, U7.2 (Q0), U8.2 (I0a), U9.2 (I0a)
/R1Q1: R18.2, U7.5 (Q1), U8.4 (I1a), U9.4 (I1a)
/R1Q2: R19.2, U7.6 (Q2), U8.6 (I2a), U9.6 (I2a)
/R1Q3: R20.2, U7.9 (Q3), U8.8 (I3a), U9.8 (I3a)
/R1Q4: R21.2, U7.12 (Q4), U8.11 (I0b), U9.11 (I0b)
/R1Q5: R22.2, U7.15 (Q5), U8.13 (I1b), U9.13 (I1b)
/R1Q6: R23.2, U7.16 (Q6), U8.15 (I2b), U9.15 (I2b)
/R1Q7: R24.2, U7.19 (Q7), U8.17 (I3b), U9.17 (I3b)
/R1Q8: R25.2, U10.2 (Q0), U11.2 (I0a), U12.2 (I0a)
/R1Q9: R26.2, U10.5 (Q1), U11.4 (I1a), U12.4 (I1a)
/R1Q10: R27.2, U10.6 (Q2), U11.6 (I2a), U12.6 (I2a)
/R1Q11: R28.2, U10.9 (Q3), U11.8 (I3a), U12.8 (I3a)
/R1Q12: R29.2, U10.12 (Q4), U11.11 (I0b), U12.11 (I0b)
/R1Q13: R30.2, U10.15 (Q5), U11.13 (I1b), U12.13 (I1b)
/R1Q14: R31.2, U10.16 (Q6), U11.15 (I2b), U12.15 (I2b)
/R1Q15: R32.2, U10.19 (Q7), U11.17 (I3b), U12.17 (I3b)
/R2-WE: U13.11 (Cp), U16.11 (Cp), U36.10
/R2Q0: R33.2, U13.2 (Q0), U14.2 (I0a), U15.2 (I0a)
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

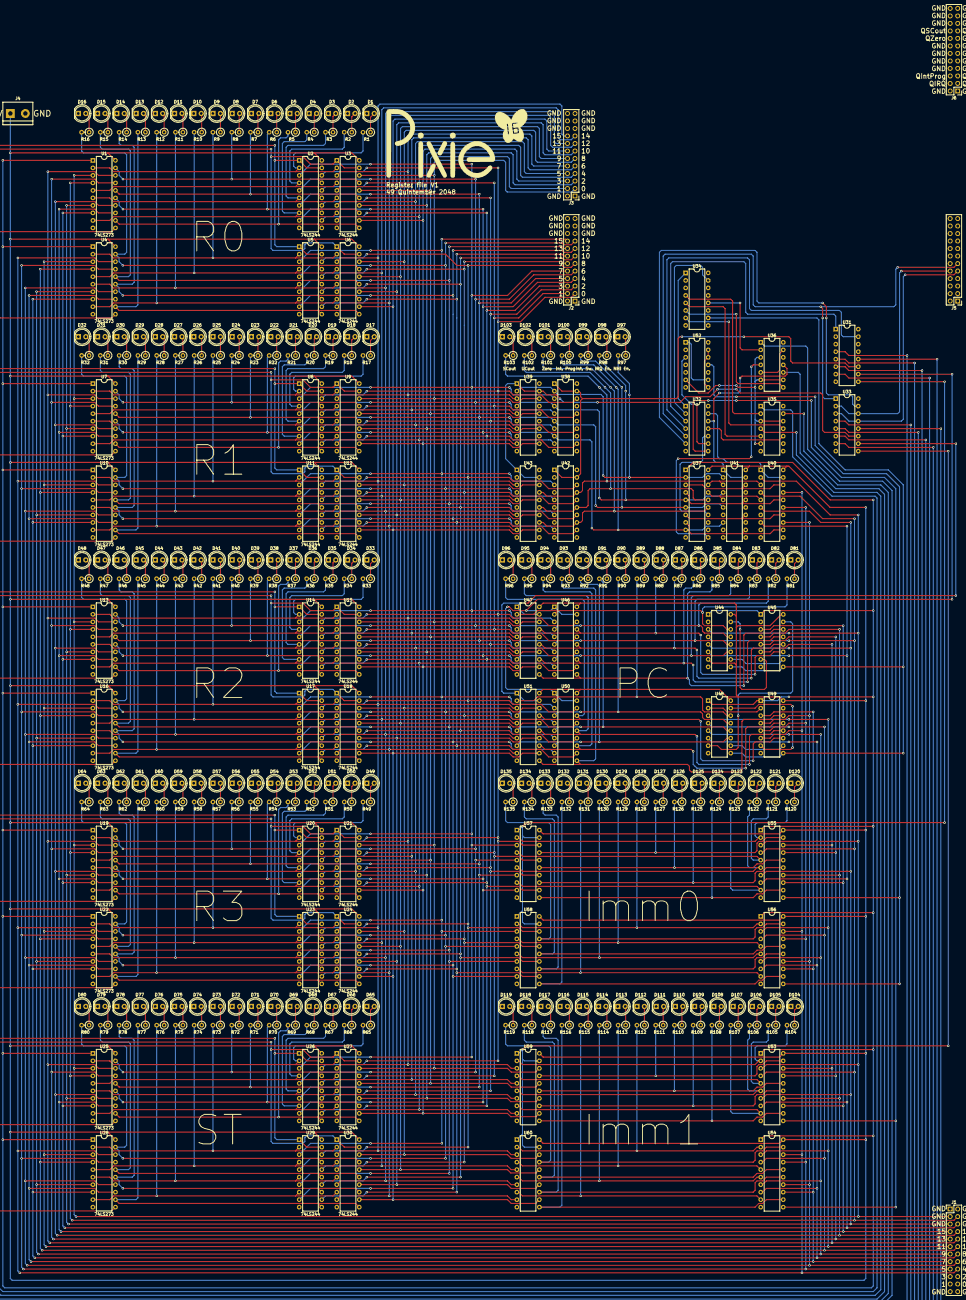
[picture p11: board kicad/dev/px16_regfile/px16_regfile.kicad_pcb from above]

Board: 2 copper layers, 337 parts (0 on the bottom side), 391 nets.

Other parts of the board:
G1: LOGO

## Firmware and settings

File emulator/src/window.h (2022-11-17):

#ifndef WINDOW_H
#define WINDOW_H

#include <stdlib.h>
#include <stdio.h>
#include <stdbool.h>
#include <stdint.h>
#include <stddef.h>

#include <X11/Xlib.h>
#include <X11/Xutil.h>
#include <X11/Xos.h>



typedef void (*button_cb_t)(void *args);

typedef enum {
	BUTTON_ART_NONE,
	BUTTON_ART_PLAY,
	BUTTON_ART_PAUSE,
	BUTTON_ART_SKIP,
	BUTTON_ART_FAST_FORWARD,
	BUTTON_ART_FAST_FORWARD_END,
} button_art_t;



typedef struct {
	// Button background color.
	uint32_t background;
	// Button border color.
	uint32_t border;
	// Button art / text color.
	uint32_t foreground;
} button_style_t;

typedef struct {
	// Inactive button.
	button_style_t inactive;
	// Active button.
	button_style_t active;
	// Hovered button.
	button_style_t hovered;
	// Pressed button.
	button_style_t pressed;
} button_styles_t;

typedef struct {
	// Window background color.
	uint32_t background;
	
	// Matrix display background color.
	uint32_t dispOff;
	// Matrix display foreground color.
	uint32_t dispOn;
	
	// Default text color.
	uint32_t text;
	// Register value color.
	uint32_t regsValue;
	// General register color.
	uint32_t regsGeneral;
	// Special register color.
	uint32_t regsSpecial;
	// Hidden register color.
	uint32_t regsHidden;
	
	// Default style for buttons.
	button_styles_t buttons;
} style_t;

typedef struct {
	// The display that this button is on.
	Display *disp;
	// The window that this button is on.
	Window   win;
	// The graphics context for this button to draw to.
	GC       gc;
	
	// The art to put on this button.
	button_art_t art;
	// The text to put on this button, if any.
	const char  *text;
	
	// Button position.
	int          x, y;
	// Button size.
	int          width, height;
	
	// Whether the button is active.
	bool         active;
	// Whether a button press has started.
	bool         pressed;
	
	// Callback for when button is pressed.
	button_cb_t  callback;
	// Context for button callback.
	void        *callback_args;
} button_t;

#define DEFAULT_BUTTON_STYLES() { \
	.inactive = { 0x2f2f2f, 0x7f7f7f, 0x7f7f7f, }, \
	.active   = { 0x2f2f2f, 0xefefef, 0xefefef, }, \
	.hovered  = { 0x3f3f3f, 0xcfcfff, 0xcfcfff, }, \
	.pressed  = { 0x000000, 0x7f7fcf, 0x7f7fcf, }, \
}

#define DEFAULT_STYLE() (style_t) { \
	.background  = 0x2f2f2f, \
	.dispOff     = 0x3f3f3f, \
	.dispOn      = 0x4f7fff, \
	.text        = 0xefefef, \
	.regsValue   = 0x4f7fff, \
	.regsGeneral = 0xefdf9f, \
	.regsSpecial = 0xef5f00, \
	.regsHidden  = 0xafafaf, \
	.buttons     = DEFAULT_BUTTON_STYLES(), \
}

extern style_t style;

void window_init();
void window_main();
void window_destroy();
void window_redraw();
bool window_poll();

#endif // WINDOW_H

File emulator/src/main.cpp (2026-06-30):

#include "main.h"
#include "runner.h"
#include "memmap.h"
#include "window.h"
#include <stdio.h>
#include <stdlib.h>
#include <time.h>
#include <sys/resource.h>
#include <unistd.h>
#include <fcntl.h>
#include <signal.h>
#include <ctype.h>
#include <string.h>
#include <termios.h>

#include <progmap.h>

double   measured_hertz;
double   target_hertz;
uint64_t sim_us_delay;
int64_t  sim_ticks;

core cpu;
memmap mem;
badge_mmap badge;

bool exuent = false;

double rolling_avg[N_ROLLING_AVG] = {0};
size_t rolling_idx = 0;
volatile bool warp_speed = false;
volatile bool running;

uint64_t sim_total_ticks = 0;

pthread_t runner_handle;

// Initial flags for termios.
struct termios origTerm;
// Is there an origTerm?
bool hasOrigTerm;
// Initial flags for STDIN.
static int fflags;
// Resets flags for STDIN.
static void resetcntl() {
    fcntl(0, F_SETFL, fflags);
	tcsetattr(0, 0, &origTerm);
}

std::string map_path;

int main(int argc, char **argv) {
	for (int i = 0; i < N_ROLLING_AVG; i++) {
		rolling_avg[i] = 0;
	}
	
	// Disable STDIN echo.
	atexit(resetcntl);
	struct termios termInfo;
	if (!tcgetattr(0, &termInfo)) {
		hasOrigTerm = false;
		origTerm = termInfo;
		termInfo.c_lflag &= ~ECHO;
		termInfo.c_lflag &= ~ICANON;
		tcsetattr(0, 0, &termInfo);
	} else {
		hasOrigTerm = true;
	}
	
	// Make STDIN nonblocking.
	fflags = fcntl(0, F_GETFL);
    fcntl(0, F_SETFL, fflags | O_NONBLOCK);
	
	// Create emulated hardware.
	running = false;
	badge_mmap_create(&badge, &mem);
	
	// PUT TEMP.
	const word rom[] = {
		// thel nop
		// 0xFFFF, 0xFFFF, 0x0003, 0x7191,
		
// FFFF FFFF 0023 0000 3FFC 0004 0084 0048
// 0030 0000 2080 3FA0 2000 0000 3180 0A00
// 0400 0A00 3180 0000 2080 3FA0 2000 0000
// 3F80 2480 2480 2080 0000 007C 0000 007C
// 0054 0074 0000 DF26 FFFF 7F05 FFFF 7FAE
// 002A 7191 7E26 FFE0 8E66 0023 03E6 FFE0
// 7010 7FAD 002C D9A6
		
		// thel scren
		0xFFFF, 0xFFFF, 0x0023, 0x0000, 0x3FFC, 0x0004, 0x0084, 0x0048,
		0x0030, 0x0000, 0x2080, 0x3FA0, 0x2000, 0x0000, 0x3180, 0x0A00,
		0x0400, 0x0A00, 0x3180, 0x0000, 0x2080, 0x3FA0, 0x2000, 0x0000,
		0x3F80, 0x2480, 0x2480, 0x2080, 0x0000, 0x007C, 0x0000, 0x007C,
		0x0054, 0x0074, 0x0000, 0xDF26, 0xFFFF, 0x7F05, 0xFFFF, 0x7FAE,
		0x002A, 0x7191, 0x7E26, 0xFFE0, 0x8E66, 0x0023, 0x03E6, 0xFFE0,
		0x7010, 0x7FAD, 0x002C, 0xD9A6,
	};
	badge.rom = rom;
	badge.rom_len = sizeof(rom) / sizeof(word);
	
	bool has_rom = false;
	bool has_map = false;
	bool start_running = false;
	
	for (int i = 1; i < argc; i++) {
		if (!strcmp(argv[i], "-h") || !strcmp(argv[i], "--help")) {
			printf("  -r           Start running immediately\n");
			printf("  -x <file>    Load executable ROM file\n");
			printf("  -m <file>    Set disassembly map file\n");
			return 1;
			
		} else if (!strcmp(argv[i], "-r")) {
			start_running = true;
			
		} else if (!strcmp(argv[i], "-x")) {
			i ++;
			if (has_rom) {
				printf("Executable file already specified\n");
				return 1;
			} else if (i < argc) {
				badge_load_rom(&badge, argv[i]);
			} else {
				printf("Missing filename for '-x'\n");
				return 1;
			}
			
			has_rom = true;
		} else if (!strcmp(argv[i], "-m")) {
			i ++;
			if (has_map) {
				printf("Map file already specified\n");
				return 1;
			} else if (i < argc) {
				map_path = argv[i];
			} else {
				printf("Missing filename for '-m'\n");
				return 1;
			}
			
			has_map = true;
		} else {
			printf("Unknown option '%s'\n", argv[i]);
			return 1;
		}
	}
	
	sim_sethertz(1000000);
	core_reset(&cpu, true);
	
	// Create runner thread.
	pthread_create(&runner_handle, NULL, &runner_main, NULL);
	running = start_running;
	
	window_main();
	
	fflush(stdout);
	
	return 0;
}


// Return unix time in seconds.
uint64_t secs() {
	struct timespec now;
	timespec_get(&now, TIME_UTC);
	return now.tv_sec;
}

// Return unix time in millisecods.
uint64_t millis() {
	struct timespec now;
	timespec_get(&now, TIME_UTC);
	return now.tv_sec * 1000 + now.tv_nsec / 1000000;
}

// Return unix time in microseconds.
uint64_t micros() {
	struct timespec now;
	timespec_get(&now, TIME_UTC);
	return now.tv_sec * 1000000 + now.tv_nsec / 1000;
}


// Sets the frequency in hertz to simulate at.
void sim_sethertz(double hertz) {
	target_hertz = hertz;
	if (hertz < 50) {
		sim_ticks = 1;
		sim_us_delay = 1000000.0 / hertz;
	} else {
		sim_us_delay = 20000;
		sim_ticks    = hertz / 50.0;
		if (!sim_ticks) sim_ticks = 1;
	}
}

// Gets the frequency in hertz to simulate at.
double sim_gethertz() {
	return target_hertz;
}

// Gets the measured frequency in hertz.
double sim_measurehertz() {
	return measured_hertz;
}

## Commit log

2022-07-14 Interrupt development.
2022-08-05 Finished interrupt implementation.
2022-08-13 Failed threading test.
2022-08-14 More testing for threading.
2022-09-02 PCB aspirations!
    [px16_regfile.kicad_pcb, px16_regfile.kicad_sch]
2022-09-03 Work on PC and PF in regfile.
    [px16_regfile.kicad_pcb, px16_regfile.kicad_sch]
2022-09-03 More development of regfile PCB.
    [px16_regfile.kicad_pcb, px16_regfile.kicad_sch]
2022-09-03 Nearly completed the regfile.
    [px16_regfile.kicad_pcb, px16_regfile.kicad_sch]
2022-09-06 Oops! DRC says your design is broken!
    [px16_regfile.kicad_pcb, px16_regfile.kicad_sch]
2022-09-07 Fix most of the tedious DRC errors.
    [px16_regfile.kicad_pcb]
2022-09-07 First complete version of regfile PCB!
2022-09-07 Small tweaks.
    [px16_regfile.kicad_sch]
2022-09-09 Start work on a smaller version of the regfile.
    [px16_regfile-B_Cu.gbr, px16_regfile-B_Mask.gbr, px16_regfile-B_Paste.gbr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]
2022-09-09 More work on regfile v2
    [px16_regfile.kicad_pcb, px16_regfile.kicad_sch]
2022-09-10 MOAR ((regfile)) ROUTING ((!))
    [px16_regfile.kicad_pcb]
2022-09-16 Generate gerber files.
    [px16_regfile-B_Cu.gbr, px16_regfile-B_Mask.gbr, px16_regfile-B_Paste.gbr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]
2022-11-13 Split emulation into it's own thread.
2022-11-13 More work on emulator interrupt support.
2022-12-18 Testing making SPACE for CAPACITOR(s)
    [px16_regfile.kicad_sch]
2022-12-19 The capaciting?
    [px16_regfile.kicad_sch]
2022-12-19 The capacitanceningification.
    [px16_regfile.kicad_sch]
2022-12-19 Add .kicad_prl to ignore because they are user preferences.
2022-12-19 Remove .kicad_prl files from the index
2022-12-19 Update fabrication files
    [px16_regfile-B_Cu.gbr, px16_regfile-B_Mask.gbr, px16_regfile-B_Paste.gbr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]
2022-12-19 Fix the location of a silkscreen item
    [px16_regfile-B_Cu.gbr, px16_regfile-B_Mask.gbr, px16_regfile-B_Paste.gbr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]
2023-03-15 Crude UART RX in emulator
